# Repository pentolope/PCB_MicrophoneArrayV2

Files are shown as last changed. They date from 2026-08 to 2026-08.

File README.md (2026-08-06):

# 16-channel circular PDM microphone array

A 120 mm circular, four-layer KiCad 10 carrier for sixteen `MSM261DHP006` PDM
MEMS microphones running at 3.3 V. A socketed Sipeed Tang Nano 9K performs
acquisition and decimation; a 2012 Raspberry Pi Model B collects the audio over
SPI0 over a 26-way cable to the Pi's P1 header.

The sixteen acoustic ports sit on a 54.00 mm radius at 22.5 degree intervals,
channel 0 on +X, numbered counter-clockwise viewed from the component side.

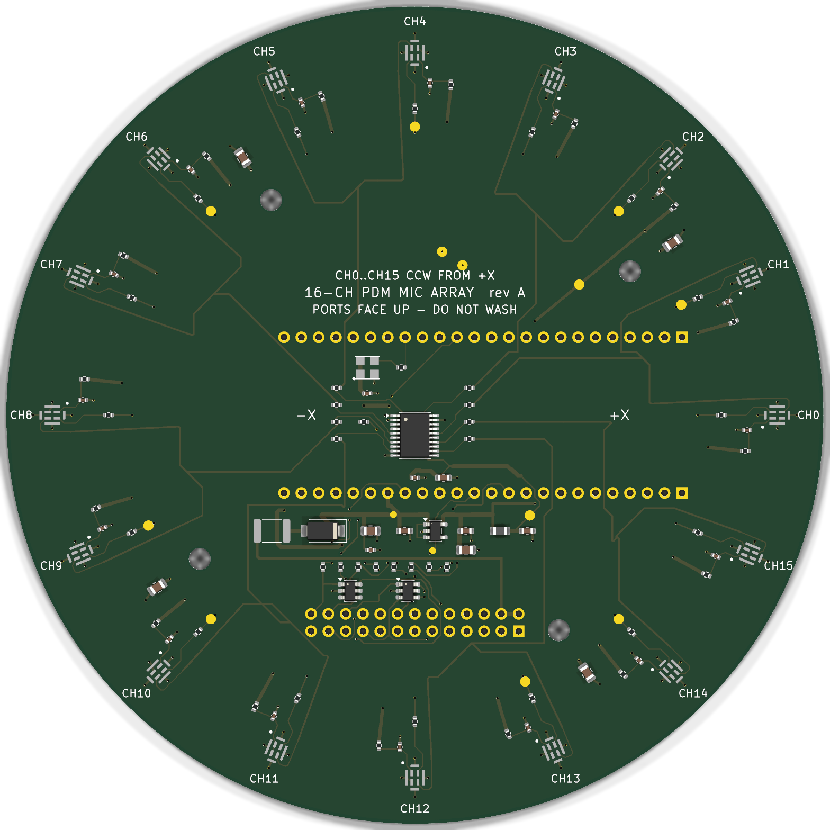
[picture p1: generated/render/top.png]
top side


## Design summary

| | |
|---|---|
| Board | 120 mm circle, 1.6 mm, 4 layers, ENIG, green / white |
| Stackup | signal / GND / GND / signal - both inner layers solid ground |
| Microphones | 16 x `MSM261DHP006`, top-ported, 3.3 V, ports up at the rim |
| Channel pairing | adjacent channels share a data line by clock edge, 8 data nets |
| Reference clock | 24.576 MHz oscillator to a global-clock FPGA pin |
| PDM clock | 3.072 MHz, buffered to 8 series-terminated branches |
| Sample rate | 48 kHz after decimate-by-64 |
| Level translation | none - microphones, FPGA banks and Pi GPIO are all 3.3 V |
| Power | Raspberry Pi 5 V only, via PTC and series Schottky |
| Microphone supply | `LP5907MFX-3.3`, 10 uVrms, 82 dB PSRR at 1 kHz |
| Host link | SPI0, 25 MHz design target, ESD-protected and series-damped |
| Assembly | all SMT on top; module sockets and Pi header hand-soldered |

The `MSM261DHP006` is a top-ported part, so "outward-facing" is realised as
ports facing up at the rim rather than radially. The capsules are
omnidirectional, so the array response is set by the port geometry, not by
package orientation; the alternative - sixteen perpendicular daughter-cards -
cannot be assembled by JLCPCB. This is discussed in
[docs/architecture.md](docs/architecture.md).

## Documentation

- [docs/architecture.md](docs/architecture.md) - signal, clock, power and
  stackup decisions, Tang Nano 9K pin assignments, and known limitations.
- [docs/host-interface.md](docs/host-interface.md) - Raspberry Pi pinout,
  bandwidth analysis and the wire protocol.
- [docs/routing.md](docs/routing.md) - what is pre-routed and why, the
  microphone escape geometry, and the FreeRouting invocation including three
  version-specific workarounds that fail silently if omitted.
- [docs/manufacturing.md](docs/manufacturing.md) - order options, order remark,
  microphone handling limits and bring-up sequence.
- [docs/sources.md](docs/sources.md) - every datasheet and manufacturer rule the
  design relies on, with the facts taken from each.

## Repository layout

| Path | Contents |
|---|---|
| `microphone_array_v2.kicad_sch` | generated schematic - do not hand-edit |
| `microphone_array_v2.kicad_pcb` | generated board - do not hand-edit, see below |
| `microphone_array_v2.kicad_pro` | project settings, net classes, design rules |
| `MicArrayV2.kicad_sym` | generated project symbols |
| `MicArrayV2.pretty/` | project footprints: microphone, oscillator, silk-free probe pads |
| `constraints.json` | frozen requirements and manufacturing profile |
| `tools/` | design source of truth, generators and checkers |
| `docs/` | engineering documentation |
| `generated/` | reports, renders and release artefacts |

## Source of truth

`tools/netlist.py` holds the complete component list, netlist and placement.
The schematic and the board are both generated from it. Nothing about the
board is edited by hand; see [the build](#building-the-board) below. Three
independent gates keep schematic and board in step:

- `tools/check_netlist_parity.py` extracts the netlist from the generated
  schematic with `kicad-cli` and compares it against `netlist.py`, including an
  exact match on which pins are deliberately left unconnected.
- KiCad's `--schematic-parity` DRC compares the board against the schematic.
- `tools/check_placement.py` re-derives the array geometry from the board:
  every microphone's acoustic port radius and azimuth, every Tang Nano 9K
  socket pin coordinate, courtyard overlaps by exact polygon distance, JLCPCB
  package-pair body spacing, and edge clearance.

`tools/check_routes.py` adds the post-route constraints KiCad cannot express:
allowed layers per net, via budgets on the clock nets, branch length matching
across the eight microphone pairs, different-net crossings, and acid traps -
corners left with an interior angle under 90 degrees.

Regeneration commands are in [docs/manufacturing.md](docs/manufacturing.md).

## Building the board

One command, from an empty directory, start to finish:

```bash
"C:/Program Files/KiCad/10.0/bin/python.exe" tools/build.py --install
```

It runs [tools/gen_pcb.py](tools/gen_pcb.py) to produce the pre-route board -
outline, stackup, footprints, placement, zones, net classes, rules, the
solder-mask via keep-outs and the declared critical routing, all locked - then
hands it to KiCad Routing Tools under the recorded plan in
[tools/routing_plan.json](tools/routing_plan.json), refills the zones and puts
the result through KiCad ERC, KiCad DRC, the critical-net contract and the
board's own manufacturability checks. The board is installed only if every gate
passes. Drop `--install` to build and check without touching the project.

Everything the run produced is kept in `build/`: the pre-route board, the routed
candidate, the plan that was executed, every command with its output, and the
validation reports.

Copper is never edited after routing. A failure is fixed in whichever input
caused it - the generator for placement and fanout, the rules or keep-outs for a
manufacturing violation, the critical-route generator for a clock, the routing
plan for anything else - and the board is built again from the beginning.

**Critical routing, and why each is generated rather than routed.** The
requirements come from `critical_routes` in
[constraints.json](constraints.json) and are checked after every build by
[tools/critical_nets.py](tools/critical_nets.py), which runs the validator's own
topology rule:

| Nets | Requirement | Why it is generated |
| --- | --- | --- |
| `MCLK_OSC`, `AUDIO_MCLK` | F.Cu, 0 vias | 24.576 MHz, the fastest edge on the board; a via would add a stub and a layer change in the middle of it |
| `PDM_CLK_FPGA`, `PDM_CLK_IN` | F.Cu, 0 vias | a TSSOP-20 pad row has 0.25 mm between pads, so the fan-in shape is decided by the package |
| `PDM_CLK_B0..7` | matched within 5 mm, F.Cu, 0 vias | inter-channel timing across the array; all eight are routed to one measured target |
| microphone escapes, supply ring, data spokes, ground stitching | mask keep-outs, 0.40 mm to any opening | the 0.566 mm ring corner and the plugged-via rule leave no room for a search |

## Status

**Generated, routed and DRC clean.** KiCad reports 0 DRC violations, 0
unconnected items and 0 schematic parity issues; ERC, netlist parity and the
placement audit all pass. Every via clears its nearest solder-mask opening by at
least 0.40 mm, so the board needs no filled-and-capped or resin-plugged process.
The eight PDM clock branches keep their intended topology - F.Cu only, zero
vias, and now matched to 1.1 mm rather than 24 mm - and both inner layers are
still solid ground.

Fourteen of the twenty-four test points are placed, each on top of a piece of
its own net so it needs no track of its own; the other ten have nowhere on the
top layer to go, and are listed in [docs/status.md](docs/status.md).

A release package is sealed at `generated/release/` — Gerbers, drills, BOM, CPL,
schematic PDF and a SHA-256 manifest, all built from one board revision in a
single run. It is a release *candidate*: JLCPCB's own part orientations cannot
be checked locally, so step through their previews before ordering. See
[docs/manufacturing.md](docs/manufacturing.md).

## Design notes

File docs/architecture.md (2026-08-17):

# Hardware architecture and engineering decisions

## Frozen requirements

- Board: 120.00 mm circular outline, 1.60 mm finished thickness, four copper
  layers, 1 oz outer / 0.5 oz inner copper, ENIG finish, green mask, white
  legend.
- Array: 16 JLCPCB-assembled `MSM261DHP006` PDM microphones running at 3.3 V,
  acoustic ports on a 54.00 mm radius at 22.5 degree intervals, channel 0 on
  +X, numbered counter-clockwise viewed from the component side.
- FPGA: Sipeed Tang Nano 9K in two hand-soldered 1x24 2.54 mm female sockets on
  the board bottom, `J2` (upper row) and `J3` (lower row).
- Host: 2012 Raspberry Pi Model B, 26-pin P1 header, SPI0 transport, on `J1` -
  a 2x13 female socket on the bottom side that mates directly onto the Pi's P1
  pins, no cable.
- Power: Raspberry Pi 5 V only.
- Assembly: every SMT part on the top side. `J1`, `J2` and `J3` are hand-fitted
  and marked DNP; all three take a 1.00 mm drill on a 2.54 mm grid.

### How "outward-facing" is realised

The `MSM261DHP006` is a **top-ported** part: its acoustic port is a 0.325 mm
hole in the lid, so its acoustic axis is normal to the PCB and cannot be made
to point radially outward on a single flat disc. The array is therefore built
with the ports facing up at the rim, on a 54 mm radius. Because the capsules
are omnidirectional, this costs nothing in directivity: the array's spatial
response is set by the geometry of the port positions, not by the orientation
of each package. Each package is additionally rotated so that its port is the
outermost feature of the footprint, with the port sitting exactly on the
54.00 mm circle. `tools/check_placement.py` asserts that radius for all 16
channels on every regeneration.

A literally radial arrangement would need sixteen small daughter-cards soldered
perpendicular at the rim, which cannot be assembled by JLCPCB and was rejected.

## Signal architecture

`MSM261DHP006` (`C22390138`) is a 4.0 x 3.0 x 1.0 mm LGA-8 part specified for
VDD 1.6 - 3.6 V, so 3.3 V is inside its normal operating range and no dedicated
microphone rail voltage is needed.

Adjacent channels form a left/right pair and share one data line. The even
channel straps `L/R` low and drives data on the falling clock edge; the odd
channel straps `L/R` high and drives on the rising edge. Sixteen microphones
therefore reach the FPGA on eight data nets, `PDM_D0` to `PDM_D7`.

**No level translation is used anywhere.** The microphones, the Tang Nano 9K
3.3 V banks and the Raspberry Pi GPIO are all 3.3 V logic. The microphone
guarantees V_OH = VDD - 0.45 V = 2.85 V against the FPGA's 2.0 V LVCMOS33 input
threshold, and accepts V_IH = 0.7 x VDD = 2.31 V against the FPGA's 3.0 V-plus
output. This removes the two 8-bit translators and one single-bit translator
that a 1.8 V microphone rail would have required.

Each microphone output has its own 22 ohm series resistor before the pair join,
so both drivers on a shared net are source-damped. Each microphone supply pin
is fed through a 100 ohm resistor with a local 100 nF capacitor, which is the
arrangement the datasheet's recommended interface circuit calls for; it forms a
16 kHz supply filter per channel and decouples the sixteen capsules from each
other on the shared rail. Four 10 uF capacitors stabilise the ring.

## Clocking

`OT322524.576MJBA4SL` (`C2831388`) supplies an exact 24.576 MHz LVCMOS clock to
FPGA pin 51 (`GCLKC_3`), a global-clock-capable input. The intended gateware
divides it by 8 to 3.072 MHz and decimates by 64 to 48.000 ksample/s.

An external oscillator is required because the Tang Nano 9K's onboard 27 MHz
reference cannot produce an exact 48 kHz family rate: 3.072 MHz / 27 MHz is
128/1125, and the GW1NR-9C rPLL cannot reach a divider of 1125.

The 3.072 MHz PDM clock leaves the FPGA on pin 35 (`GCLKT_4`), passes a 33 ohm
series resistor and drives all eight inputs of an `SN74LVC244APWR` used as a
fan-out buffer. Its eight outputs each feed one microphone pair through a
33 ohm series resistor. Driving sixteen capsules spread around a 339 mm
circumference from one FPGA pin would present roughly 100 pF of load plus a
long distributed line; the buffer splits that into eight short, individually
terminated branches. Input-to-output skew of the buffer is a few nanoseconds
against a 325 ns clock period, which is irrelevant at this rate, and the
resulting inter-channel sampling skew is far below one part in 10^4 of a
48 kHz sample.

## Power architecture

The only supply path is:

```
J1.2 and J1.4 (Pi P1 5 V) -> F1 500 mA PTC -> D1 SS14 -> +5V
+5V -> J3.18, the Tang Nano 9K 5 V header pin
+5V -> U1 LP5907MFX-3.3 -> +3V3A  (microphone ring)
+3V3A -> FB1 600 ohm bead -> +3V3_CLK  (oscillator and clock buffer)
```

`D1` is in series rather than optional. The Tang Nano 9K's USB-C connector is
still needed to load a bitstream, and its VBUS is tied to the same module 5 V
net that this board feeds. The Schottky lets whichever supply is higher win
while preventing USB VBUS from back-feeding the Raspberry Pi's 5 V rail, so a
programming cable can be plugged in without contention. `F1` protects the Pi's
own polyfuse against a fault on this board.

`U1` is an `LP5907MFX-3.3/NOPB` chosen for 10 uVrms output noise and 82 dB PSRR
at 1 kHz, feeding only the microphone ring. The oscillator and the clock buffer
are the noisy loads, so they are filtered off the same regulator through a
ferrite bead rather than the microphones being filtered from them; that puts
the filter at the aggressor.

Estimated draw: 16 microphones about 24 mA, oscillator about 15 mA, buffer
about 6 mA, Tang Nano 9K about 150 mA, total about 200 mA. This is within what
an original Model B's 5 V rail can pass, but the Pi must be fed from a supply
of at least 1.5 A. See [manufacturing.md](manufacturing.md) for the bring-up
sequence.

## Tang Nano 9K assignments

Two sets of designators are in play and they are easy to confuse. Sipeed's own
schematic calls the module's header rows **J5** and **J6**; the sockets on
*this* board that receive them are **J2** and **J3**. `J2` takes the module's
J5 row and `J3` takes its J6 row, position for position, position 1 being the
USB-C end on both. The table below is in this board's designators, because the
signal names in it are this board's nets - consult
[sources.md](sources.md) when reading Sipeed's diagram alongside it.

Only 3.3 V bank pins are used. `J3` positions 2 to 9 - the module's J6.2 to
J6.9 - are FPGA bank 3 at 1.8 V and are deliberately left unconnected, as are
the TF-card and HDMI-multiplexed pins.

Two rules set the assignment. The eight data lines are spread across **both**
header rows and ordered along each row to follow the azimuth of the channels
they serve: the four upper pairs land on `J2` and the four lower pairs on `J3`.
Putting all eight on adjacent pins of one row forces every line from the lower
rim to travel the length of the module and cross its neighbours. Separately,
**every host signal is on `J3`**, the row facing the Pi header, and **both
clocks are on `J2`**; leaving SPI on the upper row made those lines cross the
whole board, out from `J1` at the bottom, past the header and both socket rows,
to reach it.

| Carrier signal | Module header | FPGA pin | Direction |
|---|---:|---:|---|
| `PDM_D0` (CH0/1, azimuth 11 deg) | J2.5 | 25 | input |
| `PDM_D1` (CH2/3, 56 deg) | J2.9 | 29 | input |
| `PDM_CLK_FPGA` | J2.14 | 35 (`GCLKT_4`) | output |
| `AUDIO_MCLK` | J2.17 | 51 (`GCLKC_3`) | input, global clock |
| `PDM_D2` (CH4/5, 101 deg) | J2.19 | 54 | input |
| `PDM_D3` (CH6/7, 146 deg) | J2.23 | 68 | input |
| `PDM_D7` (CH14/15, 326 deg) | J3.1 | 63 | input |
| `PDM_D6` (CH12/13, 281 deg) | J3.10 | 77 | input |
| `HOST_SYNC` | J3.11 | 76 | output |
| `HOST_STATUS` | J3.13 | 74 | output |
| `SPI_MOSI` | J3.14 | 73 | input |
| `HOST_IRQ` | J3.15 | 72 | output |
| `SPI_CS_N` | J3.16 | 71 | input |
| `HOST_RESET_N` | J3.17 | 70 | input |
| `+5V` | J3.18 | power | input to module |
| `SPI_SCLK` | J3.19 | 48 | input |
| `SPI_MISO` | J3.20 | 49 | output |
| `PDM_D5` (CH10/11, 236 deg) | J3.21 | 31 | input |
| `PDM_D4` (CH8/9, 191 deg) | J3.22 | 32 | input |
| `GND` | J3.23 | power | return |
| `TANG_3V3` | J3.24 | power | ESD clamp reference only |

The host block on `J3.11` to `J3.20` is in the same left-to-right order as the
series-damping resistor row that feeds it, so those runs do not cross.

FPGA pins 68, 70, 71, 72 and 75 are shared with the module's HDMI connector.
Four of them are used - 68 (`PDM_D3`), 70 (`HOST_RESET_N`), 71 (`SPI_CS_N`) and
72 (`HOST_IRQ`) - and driven as ordinary 3.3 V GPIO they carry an unterminated
stub to that connector, which is immaterial at the 3.072 MHz PDM rate and for
the DC-ish control lines. Pin 75 is not used at all. Both clock inputs are kept
off HDMI-shared pins, and so are the two 25 MHz SPI signals whose edges the
link actually depends on, `SPI_SCLK` (48) and `SPI_MISO` (49). `SPI_CS_N` is
the one SPI line on a shared pin; it is static for the duration of a burst. The
microSD pins (`J2.1`-`J2.4`) are left alone so the module's card socket stays
usable.

Socket position 1 is the module's USB-C end on both rows, matching Sipeed's
published pin diagram. `tools/check_placement.py` asserts that `J2` and `J3`
land on their expected board coordinates, and the net assignment above is
generated from `TANG_NET_MAP` in `tools/design.py`, which is the authority for
it.

### Known limitation: module ground return

The Tang Nano 9K exposes exactly one ground pin across both header rows
(`J3.23`). Every signal between the carrier and the module shares that single
return. This is a property of the module, not of this board. It is mitigated by
keeping both inner layers as solid ground directly under the module, by series
damping every fast net, and by keeping the SPI runs between the module socket
and the host header short. It remains the weakest part of the interconnect and is the
first thing to examine if high-rate SPI proves marginal.

## Layer usage and return paths

| Layer | Function |
|---|---|
| `F.Cu` | All components, primary routing, all clock nets |
| `In1.Cu` | Solid ground plane |
| `In2.Cu` | Solid ground plane |
| `B.Cu` | Secondary routing; no components |

This deliberately departs from the more usual signal / ground / power / signal
arrangement. The whole board draws about 200 mA, so the supplies are entirely
comfortable as 0.6 mm tracks, and dedicating the second inner layer to ground
instead buys an unbroken reference plane adjacent to **both** routing layers.
No PDM clock or data line can then cross a plane split, and the return current
for any trace on either outer layer has a continuous path directly beneath it.
Power-plane impedance, which is what the conventional stackup would buy, is not
a constraint at this current.

Ground is a plane net that the autorouter never sees. Because a plane on an
inner layer cannot reach a surface-mount pad on its own, `tools/gen_pcb.py`
places an explicit stitching via plus a short connecting track at every ground
pad - 110 of them - choosing each via position by scoring candidate directions
against all neighbouring pads rather than by a fixed offset.

Track widths come from net classes: 0.60 mm for supplies, 0.25 mm for the
per-channel microphone feeds and the clock nets, 0.20 mm elsewhere. Routing
vias are 0.45 mm pad on a 0.30 mm finished hole and are tented on both sides.
Copper-to-edge target is 0.30 mm.

## Test provisions

Twenty-four top-side test pads on two arcs expose the three supply rails, the
Tang 3.3 V sense, two grounds, the 24.576 MHz reference, the 3.072 MHz PDM
clock, all eight PDM data lines and all eight host signals. Each is labelled on
the silkscreen with a short mnemonic; the full net name is carried on the
fabrication layer.

## Primary sources

See [sources.md](sources.md) for the datasheets, JLCPCB capability pages and
Sipeed documentation this design was built from, with retrieval dates.

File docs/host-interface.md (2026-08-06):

# Raspberry Pi host interface

## Physical connection

`J1` is a 2x13, 2.54 mm pin header on the board bottom, hand-soldered and
marked DNP for assembly. A 26-conductor cable connects it to the P1 header of
a 2012 Raspberry Pi Model B. Pin 1 is marked on the silkscreen and by a square
pad.

Mating the two boards directly instead, which the HOST_DIRECT_STACK contract
asks for, is the better link electrically - it would remove about 150 mm of
unshielded cable and its shared return - but it is not a connector swap. It
needs the host fan re-laid for a socket's mirrored pin rows, and it needs the
Tang Nano 9K off the underside, because that is where the Raspberry Pi would
be. Recorded in [status.md](status.md).

Only pins that are identical on Model B revision 1.0 and revision 2.0 are used,
so the board works with either. In particular the revision-dependent pins 3, 5
and 13 are left unconnected, and the P5 header carrying I2S is not used at all -
that header does not exist on revision 1.0 boards.

| Pi physical pin | BCM signal | Array function | Direction at Pi |
|---:|---|---|---|
| 2, 4 | 5V | board supply | power out |
| 6, 9, 14, 20, 25 | GND | return | power |
| 16 | GPIO23 | `HOST_SYNC` | input |
| 18 | GPIO24 | `HOST_STATUS` | input |
| 19 | GPIO10 / MOSI | `SPI_MOSI` | output |
| 21 | GPIO9 / MISO | `SPI_MISO` | input |
| 22 | GPIO25 | `HOST_IRQ` | input |
| 23 | GPIO11 / SCLK | `SPI_SCLK` | output |
| 24 | GPIO8 / CE0 | `SPI_CS_N` | output |
| 26 | GPIO7 / CE1 | `HOST_RESET_N` | output |

Pin 1 (3V3) is deliberately **not** connected. The ESD arrays clamp to the
board's own `TANG_3V3` rail instead, which is present whenever the board is
powered; clamping to the Pi's 3.3 V would pull the signals towards 0.7 V if the
Pi were unpowered while the module was running from USB.

Every host line carries a 33 ohm series resistor at the connector and passes
through one of two `USBLC6-4SC6` four-channel ESD arrays.

## Bandwidth and clock rate

The sustained payload at full rate is

```
16 channels x 48000 samples/s x 16 bits = 12.288 Mbit/s
```

A 2012 Model B drives SPI0 from a 250 MHz core clock divided by an even
integer, so the usable settings near the top are 15.625 MHz (divider 16) and
25 MHz (divider 10).

- At **25 MHz** the payload occupies about 49 % of the link, which leaves
  comfortable headroom for framing and for the Pi's DMA servicing.
- At **15.625 MHz** it occupies about 79 %, which is workable but tight.
- Decimating to 16 kHz in the FPGA instead reduces the payload to 4.096 Mbit/s
  and runs comfortably at any supported clock.

The hardware is designed for 25 MHz: series damping on every line, ESD arrays
with 3 pF loading, and short runs between the socket and the connector. Whether
25 MHz is actually reliable depends on cable length and on the single-ground
return described in [architecture.md](architecture.md); treat 16 kHz mode as
the fallback if it is not.

## Proposed wire protocol

This repository freezes the electrical interface and pin constraints. The
gateware implementation can evolve without a board revision.

- SPI mode 0, MSB first, 25 MHz maximum.
- The FPGA raises `HOST_IRQ` when at least one complete frame is buffered.
- The Pi asserts `SPI_CS_N` and clocks a fixed 32-byte header followed by the
  payload.
- `HOST_RESET_N` is active low and resets the acquisition FIFO without
  reconfiguring the FPGA.
- `HOST_SYNC` pulses on the first sample of a frame; `HOST_STATUS` is high while
  acquisition is locked to the 24.576 MHz reference.

Header fields are little-endian after the byte-oriented magic:

| Offset | Size | Field |
|---:|---:|---|
| 0 | 4 | ASCII `PDM1` |
| 4 | 2 | protocol version, initially 1 |
| 6 | 2 | header size, 32 |
| 8 | 4 | frame sequence number |
| 12 | 4 | sample sets in payload |
| 16 | 8 | running 48 kHz sample counter |
| 24 | 4 | status flags: overflow, clock fault, reset seen |
| 28 | 4 | CRC-32 of payload, or zero when disabled |

The payload is interleaved signed 16-bit PCM: sample set 0 channels 0 to 15,
then sample set 1, and so on. Channel *n* is the microphone whose acoustic port
lies at azimuth 22.5*n* degrees counter-clockwise from +X.

## Channel-to-edge mapping in gateware

Each PDM data line carries two channels multiplexed by clock edge:

| Data net | Falling edge (`L/R` low) | Rising edge (`L/R` high) |
|---|---|---|
| `PDM_D0` | CH0 | CH1 |
| `PDM_D1` | CH2 | CH3 |
| `PDM_D2` | CH4 | CH5 |
| `PDM_D3` | CH6 | CH7 |
| `PDM_D4` | CH8 | CH9 |
| `PDM_D5` | CH10 | CH11 |
| `PDM_D6` | CH12 | CH13 |
| `PDM_D7` | CH14 | CH15 |

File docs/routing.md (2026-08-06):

# Routing methodology

> **The router is now KiCad Routing Tools, driven by
> [tools/routing_plan.json](../tools/routing_plan.json) from
> [tools/build.py](../tools/build.py).** The FreeRouting flow described from
> *Exporting* onwards is kept as the record of how Rev A was first routed; it
> is not the flow in use. See "Building the board" in the
> [README](../README.md).

## Authority

KiCad owns the board. The router may add tracks and vias and nothing else.
Every candidate is routed into a *copy* of the pre-route board, and the build
compares the two: footprints, outline, netlist, stackup and origin must be
untouched, or the candidate is rejected.

## What is pre-routed, and why

Three classes of copper are placed deterministically by `tools/gen_pcb.py`
rather than by the autorouter:

**Ground stitching.** Ground is a plane net that the autorouter is told to
ignore, and an inner plane cannot reach a surface-mount pad by itself. Every
ground pad therefore gets its own via plus a short connecting track. Via
direction is chosen along the pad's own axes, never diagonally: a diagonal
crosses the neighbouring pin on a fine-pitch package, and on the microphone it
lands in the corner channel the signal pads need.

**Microphone L/R straps.** Pad 2 sits inside the ground ring with a 0.40 mm gap
around it, so it cannot reach a via of its own, and it must not consume one of
the four diagonal corners. It is always on the same net as a neighbour it can
be joined to directly: ground (pad 6) on even channels, the supply pad on odd
channels.

**Microphone escapes.** This is the critical one. The `MSM261DHP006` land
pattern encloses its four signal pads in a ring of ground pads. The straight
gaps are 0.40 mm, which fits no track at all once clearance is counted. The
only way out is the diagonal corner between a side bar and an end bar, which
measures 0.566 mm - enough for a 0.15 mm track with 0.15 mm clearance and
nothing more.

FreeRouting cannot handle those corners in either direction:

- It will not create the escapes itself. It approximates pad outlines with
  bounding octagons (`ShapeSearchTree45Degree.complete_shape: non-IntOctagon
  contained shape, using bounding octagon approximation`), which closes the
  diagonal gap. Left to itself it reports "no connection was found between
  their nets" and finishes with all sixteen microphone clock and data nets
  unrouted.
- It will not accept them as existing wiring either. Given a DSN containing
  them it stalls indefinitely at `Wiring: normalization of net 'PDM_CLK_B3'
  failed` and never starts a routing pass.

The resolution is a handover point. The board given to the autorouter
(`gen_pcb.py --no-escapes`) contains, for each microphone:

- a **via** on each of the three signal nets, sitting where that escape will
  end, just outside the package. A bare via is geometry FreeRouting handles
  without complaint, so it happily routes the rest of each net up to it;
- a **keepout rule area** covering the corridor between the ring and those
  vias, so nothing else is routed through the space the escapes need.

After the candidate is merged, `tools/apply_escapes.py` deletes the keepouts
and draws the escapes into the corridor they reserved, terminating exactly on
the handover vias.

Applying the escapes without reserving the corridor first does not work: the
autorouter fills that space with other nets, and the result came back with 57
shorting-item violations and 103 crossing tracks.

The geometry is identical for all sixteen channels and is generated in
footprint-local coordinates:

| Pad | Path |
|---|---|
| 1 (VDD) | inward through the pad 5 / pad 6 corner |
| 4 (DATA) | inward through the pad 5 / pad 8 corner |
| 3 (CLK) | outward through the pad 7 / pad 8 corner, then up the outside of the left ground bar |

The clock pad needs the detour because it sits on the outward half of the
package while its resistor is inboard. Every corner waypoint is the exact
midpoint of the 0.566 mm gap, giving 0.208 mm to each ground pad, and every
segment is at 45 degrees or orthogonal.

The per-channel 100 nF capacitor is rotated 180 degrees so that its ground pad
- and therefore its stitching via - faces radially inward instead of sitting in
the clock escape corridor.

## FreeRouting invocation

FreeRouting 2.2.4 is pinned by SHA-256 (see [sources.md](sources.md)).

```
java -Xss256m -Xmx6g -jar freerouting-2.2.4.jar --gui.enabled=false \
     -de board.dsn -do board.ses -drc fr-drc.json \
     -mp 6 -mt 4 -inc PLANE
```

`-Xss256m` is required, not an optimisation. With the default thread stack,
FreeRouting 2.2.4 dies about two seconds after loading this board with a
`StackOverflowError` in `PolylineTrace.combine`, recursing on the pre-routed
microphone escapes. The recursion is deep rather than infinite, so a larger
stack clears it; without the flag no candidate is produced at all.

Two constraints have to be applied to the DSN rather than the command line,
because **this version silently ignores the options that would express them**:

- `--router.layers.routable=true,false,false,true` is rejected with
  "Unknown settings property: router.layers.routable ... No field found with
  name or SerializedName: layers", and routing proceeds on all four layers -
  including both ground planes. `tools/patch_dsn.py` instead rewrites the two
  inner layers from `(type signal)` to `(type power)`, which FreeRouting does
  honour.
- KiCad does not carry a track's locked flag into the DSN; every wire exports
  as `(type route)`, which FreeRouting is free to rip up. The same script
  promotes them to `(type protect)`.

`-random_seed` is also rejected by this version, so candidates are varied by
pass count rather than by seed.

Always check the FreeRouting log for `Unknown command line argument` and
`Unknown settings property` warnings. They are warnings, not errors, and the
run continues with the constraint silently dropped. The first routing attempt
on this board ran to completion on all four layers, ground planes included,
because of exactly that.

## End-to-end sequence

```bash
python tools/gen_pcb.py --no-escapes
python tools/kicad_specctra.py export microphone_array_v2.kicad_pcb generated/route/board.dsn
python tools/patch_dsn.py generated/route/board.dsn GND1 GND2
java -Xss256m -Xmx6g -jar freerouting-2.2.4.jar --gui.enabled=false \
     -de generated/route/board.dsn -do generated/route/seed17.ses \
     -drc generated/route/fr-drc.json -mp 6 -mt 4 -inc PLANE
python tools/kicad_specctra.py import microphone_array_v2.kicad_pcb \
     generated/route/seed17.ses generated/route/routed17.kicad_pcb
python tools/merge_routing.py microphone_array_v2.kicad_pcb \
     generated/route/routed17.kicad_pcb generated/route/merged17.kicad_pcb
python tools/kicad_specctra.py compare microphone_array_v2.kicad_pcb \
     generated/route/merged17.kicad_pcb        # must report invariants_equal
python tools/apply_escapes.py generated/route/merged17.kicad_pcb
python tools/check_routes.py generated/route/merged17.kicad_pcb
```

## Why the candidate is merged rather than used directly

**KiCad's SES import must not be allowed to own placement.** Specctra stores
component rotation in whole degrees, and KiCad re-applies the session file's
placement on import. This board is built on 22.5 degree steps, so importing a
candidate silently rounds 33.75 degrees to 34.0 and moves 88 of the 134
footprints. The invariant comparison catches it - `changed_invariants:
["footprints"]`.

`tools/merge_routing.py` therefore keeps the pre-route board as the authority
for footprints, outline, zones and nets, and transplants only the tracks and
vias from the candidate. After merging, the semantic snapshot hash matches the
pre-route board exactly.

Re-running `gen_pcb.py` regenerates the board from the netlist and discards all
routing, so it must not be run after a candidate has been promoted.

## Post-route gates

`tools/check_routes.py` enforces the constraints KiCad's DRC cannot express:

- tracks only on `F.Cu` and `B.Cu`;
- `AUDIO_MCLK` and `MCLK_OSC` on `F.Cu` with zero vias;
- via budgets on the PDM clock nets;
- length spread across the eight clock branches within 6 mm;
- no segment shorter than 0.05 mm and no corner sharper than 45 degrees;
- the ground stitching still intact.

KiCad's own DRC is then the authority for clearance, shorts, holes, edge
clearance and schematic parity, run with `--all-track-errors`,
`--schematic-parity`, `--severity-all` and zero tolerated violations.

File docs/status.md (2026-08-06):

# Status: routed, DRC clean, release sealed

All 270 connections are routed. KiCad reports **0 DRC violations, 0 unconnected
items and 0 schematic parity issues**, with zones refilled. A fabrication
package is sealed at `generated/release/`; see
[manufacturing.md](manufacturing.md).

| Gate | Result |
|---|---|
| Schematic ERC | 0 violations |
| Board DRC (errors + warnings) | 0 violations |
| Unconnected items | 0 |
| Schematic parity | 0 issues |
| Netlist parity, schematic vs `tools/netlist.py` | clean, 83 nets, 124 components |
| Placement and array geometry audit | clean, 124 footprints |
| Clock branch layers and via budget | clean - zero vias, F.Cu only |
| Clock branch length matching | 21.5 mm spread against a 25 mm limit |
| PDM data length | clean |
| Different-net crossings | none |
| Acid traps (interior angle < 90 deg) | none |
| Track segments under 0.05 mm | none |

Copper: 2555 mm over 1000 segments, 184 vias. Both inner layers are still solid
ground, no tracks on either. 124 footprints, including 14 probe pads.

## How it got here

The generated routing in `tools/gen_pcb.py` closed the microphone array, the
clock tree, the data spokes, the supply ring and the power block, but left the
host block open - 73 connections. Those were finished with an external
autorouter, and the test points were removed at the same time. Fourteen of
them are now back, placed against the routed copper - see below.

The autorouter left the parts that matter alone. All eight PDM clock branches
are still F.Cu only with zero vias, and each PDM data net still uses exactly
two. Net classes, via geometry (0.45 mm pad / 0.30 mm drill throughout) and the
ground planes came through untouched.

## What was repaired afterwards

`tools/patch_board.py` fixes the board in place, because it is no longer
regenerated from the netlist. It found and fixed:

- **Two hard shorts.** A ground stitching via and its stub sat on U1 pin 3, tying
  the regulator's enable pin to ground - the whole 3.3 V rail would have been
  dead. Another shorted the 5 V input lane to ground. Both come from the
  `POWER_ROW_REFS` special case in `place_ground_stitching()`, which pushes the
  via 1.45 mm straight down with no obstacle test at all, even though the
  function builds an obstacle list a few lines earlier. Moving
  `POWER_ROW2_Y` from -20.2 to -19.8 mm, to open the 5 V lane, is what put the
  second one on top of that lane.
- **A third instance of the same defect**, 0.067 mm from RH4's SPI_MISO pad.
- **Three clearance failures caused by a single wrong constant.** The generator
  checks everything against `TRACK_CLEARANCE = 0.15`, but POWER wants 0.25 mm and
  Default 0.20 mm, so near misses against those nets passed the guard and
  failed DRC. The +3V3A feed threading the module socket needed 1.30 mm of the
  1.27 mm between two pins; it is now 0.25 mm wide and fits.
- **A dangling 1.6 mm tail** on the +5V bus, left over from turning D1 round so
  its anode faces the fuse.
- **Two 0.3 mm drills 0.204 mm apart** where the supply feed landed on its own
  via next to the ring's. Same net, so the feed now runs into the ring's via.

## Test points

14 of the 24 are back, placed by `tools/place_testpoints.py`. It does not put
them on a ring any more. Each pad goes **on top of a piece of its own net that
is already routed**, so it needs no track of its own - which turns the problem
from "can this be wired" into "is there room", and removes any chance of a
probe pad shorting something on the way to its net. GND is the exception: the
planes run under the whole board, so its two pads take a via of their own and
can go anywhere clear.

A candidate has to clear every other net by that pair's net class clearance,
keep its courtyard out of every other courtyard, stay outside the Tang Nano's
70 x 26 mm outline so a probe can physically reach it, and hold 2.5-3.5 mm from
the other pads. Where a 1.5 mm pad will not fit, a 1.0 mm one is tried.

The pads carry no silkscreen - the stock outline collides with the legend of
whatever they are tucked beside - so they use silk-free variants saved in
`MicArrayV2.pretty` rather than locally edited copies, which keeps KiCad from
reporting that the board no longer matches its library. Positions are on the
fabrication layer and in `generated/test_points.py`.

**Ten nets have no probe pad.** `AUDIO_MCLK` and `PDM_CLK_IN` live entirely in
the central cluster, underneath the FPGA module, so nothing on the top layer
can reach them. `TANG_3V3`, `SPI_SCLK`, `SPI_MOSI`, `SPI_MISO`, `SPI_CS_N`,
`HOST_IRQ`, `HOST_SYNC` and `HOST_RESET_N` run through the host block, which is
too dense for even a 1.0 mm pad. All eight host signals are still reachable at
the Pi header itself, and the clocks at the module socket pins once the module
is unplugged.

## The cleanup pass

`tools/cleanup_tracks.py` tidied the copper the autorouter left, in four passes
that each stay inside the shape the copper already occupied, so nothing that
passed clearance before could fail after:

| | before | after |
|---|---:|---:|
| Segments under 0.05 mm | 31 | **0** (shortest is now 0.071 mm) |
| Corners with interior angle < 90° | 30 | **2**, both on via copper |
| Segments retracing themselves | 3 | **0** |
| Collinear joins | 78 | 10 |
| Track segments | 1099 | 1000 |

Endpoints within 60 µm are snapped together, which is what removes the slivers -
they are wider than a coincidence tolerance would catch. Collinear pairs merge,
retraces drop, and any corner still turning more than 90° has its tip cut off
by a short chord, splitting it into two corners of half the angle.

The two acute corners that remain sit on vias, where the round pad copper fills
the notch, so there is nothing to trap etchant. `check_routes.py` now tests for
that condition rather than for the old 45° grid rule: the host block came from
an external autorouter and is not on the grid, so a grid rule described a style
the board no longer has. 69 corners are off-grid and none of them is acute.

## Still outstanding

Nothing that fails a gate. Worth knowing:

- **Clock branch spread is 21.5 mm**, up from 7.1 mm, because branches 5 and 6
  take lateral corridors around the host block. Inside the 25 mm limit, and
  21.5 mm of FR-4 is about 130 ps against a 325 ns PDM clock period, but the
  margin is thinner than it was.
- **`PDM_CLK_IN` uses 3 vias.** Its budget was 2 and is now 4, with the reason
  recorded in `check_routes.py`: the buffer's inputs interleave with its outputs
  on 0.65 mm pitch, so the input bus has to leave on the bottom layer. That is a
  different case from a clock branch fanning out into open board, which still
  takes none.
- **The release is a candidate, not approved production data.** Everything that
  can be checked locally has been; what cannot is whether each LCSC part's zero
  orientation in JLCPCB's library matches the rotation in `cpl.csv`. That needs
  their live preview.

## Open: the host connector

`verification/boards/live.json` carries a `HOST_DIRECT_STACK` contract that
requires `J1` to be a female 2x13 socket the array plugs straight onto the Pi
with. The board has a male pin header and a cable. The contract is the better
link electrically, and it is not a footprint swap:

- **The pin rows mirror.** KiCad's `PinSocket_2x13_P2.54mm_Vertical` numbers
  its second row on the opposite side of the first (pin 2 at x = -2.54 rather
  than +2.54) - that mirroring is what lets a socket mate face-to-face with a
  header. Swapping the footprint moves every even pin to the other column, and
  the host resistor fan, which is ordered to leave in signal order, has to be
  re-laid to match. Tried: the generator loses the `PI_5V` feed and every clock
  branch to the reshuffled Pi header band.
- **The Raspberry Pi would be where the Tang Nano 9K is.** `J1`, `J2` and `J3`
  are all on the underside. With a cable that is fine; stacked directly, the
  module in its sockets and the Pi's board occupy the same space under the
  array. Direct stacking needs the module moved to the top side, or standoffs
  and a taller socket, and either is a placement change rather than a wiring
  one.

Until that is decided the board keeps the header and the cable, and
`CONTRACT.CONNECTOR` keeps failing - honestly, because the two really do
disagree.

## Reproducibility

**The board is rebuilt from `tools/netlist.py` on demand.** One command,
`tools/build.py --install`, generates the pre-route board, hands the ordinary
nets to KiCad Routing Tools under the recorded plan, and installs the result
only if every gate passes. Nothing in the `.kicad_pcb` is hand-edited, and the
notes above about patching and cleaning copper describe how the board was first
brought up, not how it is maintained. The schematic is generated the same way,
by `tools/gen_schematic.py`, and netlist parity passes.

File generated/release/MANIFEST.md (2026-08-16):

# Fabrication release manifest

- generated: 2026-08-16T20:39:30.252617+00:00
- kicad: 10.0.5
- constraint profile: jlcpcb-4layer-assembled
- source closure sha256: `bd2afdef6dd0df0d8387ff560c4591d102f493100dba02cb8e9492ddbcf32d9b`

## command

    kicad-cli.exe sch erc --output C:\Users\pentolope\Documents\GitHub\PCB_MicrophoneArrayV2\verification\out\microphone-array-v2-live\attempts\20260816T203906Z-9bcc9db5\work\clean_run\reports\erc.json --format json --severity-all --severity-exclusions --exit-code-violations C:\Users\pentolope\Documents\GitHub\PCB_MicrophoneArrayV2\verification\out\microphone-array-v2-live\attempts\20260816T203906Z-9bcc9db5\work\clean_run\fixture\project\microphone_array_v2.kicad_sch
    kicad-cli.exe pcb drc --output C:\Users\pentolope\Documents\GitHub\PCB_MicrophoneArrayV2\verification\out\microphone-array-v2-live\attempts\20260816T203906Z-9bcc9db5\work\clean_run\reports\drc.json --format json --severity-all --severity-exclusions --all-track-errors --schematic-parity --refill-zones --save-board --exit-code-violations C:\Users\pentolope\Documents\GitHub\PCB_MicrophoneArrayV2\verification\out\microphone-array-v2-live\attempts\20260816T203906Z-9bcc9db5\work\clean_run\fixture\project\microphone_array_v2.kicad_pcb
    kicad-cli.exe pcb export gerbers --output C:\Users\pentolope\Documents\GitHub\PCB_MicrophoneArrayV2\verification\out\microphone-array-v2-live\attempts\20260816T203906Z-9bcc9db5\work\clean_run\generated\gerbers --layers F.Cu,In1.Cu,In2.Cu,B.Cu,F.Paste,B.Paste,F.Silkscreen,B.Silkscreen,F.Mask,B.Mask,Edge.Cuts --no-x2 --no-netlist --use-drill-file-origin --subtract-soldermask C:\Users\pentolope\Documents\GitHub\PCB_MicrophoneArrayV2\verification\out\microphone-array-v2-live\attempts\20260816T203906Z-9bcc9db5\work\clean_run\fixture\project\microphone_array_v2.kicad_pcb
    kicad-cli.exe pcb export drill --output C:\Users\pentolope\Documents\GitHub\PCB_MicrophoneArrayV2\verification\out\microphone-array-v2-live\attempts\20260816T203906Z-9bcc9db5\work\clean_run\generated\gerbers --format excellon --excellon-separate-th --drill-origin plot C:\Users\pentolope\Documents\GitHub\PCB_MicrophoneArrayV2\verification\out\microphone-array-v2-live\attempts\20260816T203906Z-9bcc9db5\work\clean_run\fixture\project\microphone_array_v2.kicad_pcb
    kicad-cli.exe pcb export pos --output C:\Users\pentolope\Documents\GitHub\PCB_MicrophoneArrayV2\verification\out\microphone-array-v2-live\attempts\20260816T203906Z-9bcc9db5\build\cpl.csv --format csv --units mm --side both --exclude-dnp C:\Users\pentolope\Documents\GitHub\PCB_MicrophoneArrayV2\verification\out\microphone-array-v2-live\attempts\20260816T203906Z-9bcc9db5\work\clean_run\fixture\project\microphone_array_v2.kicad_pcb
    kicad-cli.exe sch export bom --output C:\Users\pentolope\Documents\GitHub\PCB_MicrophoneArrayV2\verification\out\microphone-array-v2-live\attempts\20260816T203906Z-9bcc9db5\build\bom.csv --fields ${QUANTITY},Reference,Value,Footprint,LCSC --labels "Quantity,Designator,Comment,Footprint,LCSC Part #" --group-by Value,Footprint,LCSC --exclude-dnp --ref-range-delimiter  C:\Users\pentolope\Documents\GitHub\PCB_MicrophoneArrayV2\verification\out\microphone-array-v2-live\attempts\20260816T203906Z-9bcc9db5\work\clean_run\fixture\project\microphone_array_v2.kicad_sch
    rename "13 file(s)"
    orient "103 placement(s)"
    relabel cpl.csv
    relabel bom.csv

## artifacts

- `microphone_array_v2-revA-fabrication.zip` sha256 `2770680dd784fc3fad6d0e4c3f940c4180ad91361ebe8b3abbd9bba7cd0fa03d`
- `bom.csv` sha256 `a3970d865b3b76677afe0b11b6061156e3be633a50613167887ef8a54fe14563`
- `cpl.csv` sha256 `28091e4dbf5a05e30af72f833839194c67c0aa0f90c6f797d0434fce84e7e807`

## excluded from the archive

- `(none)`: every exported layer was approved

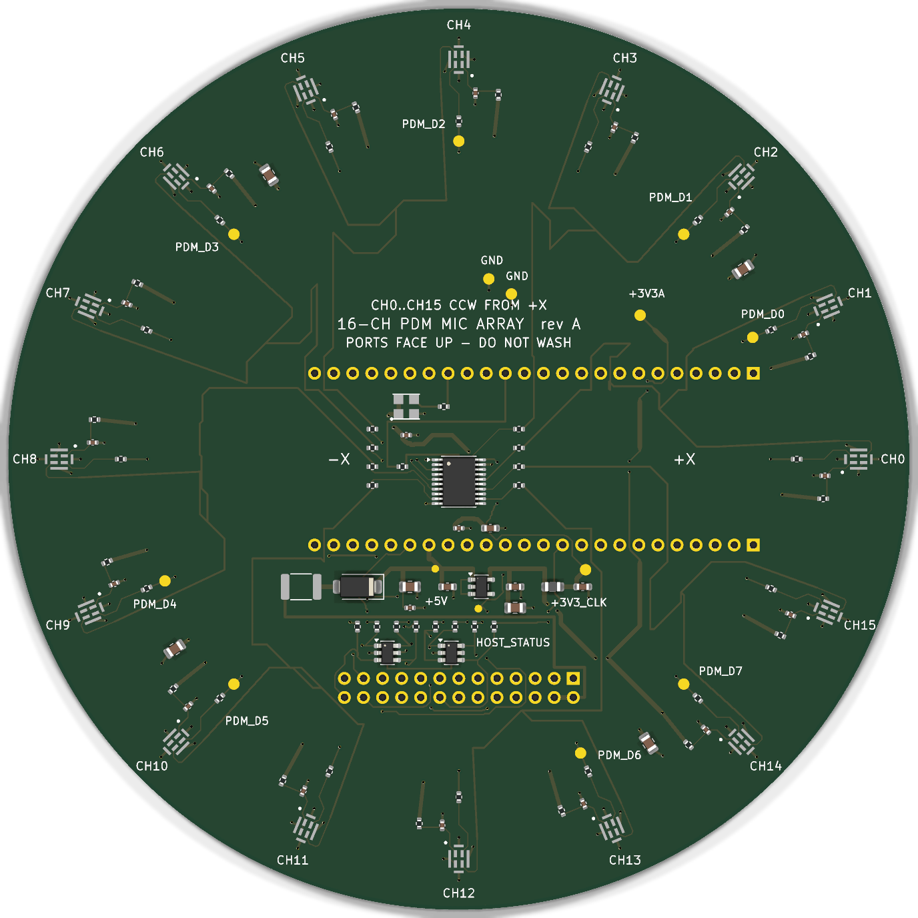
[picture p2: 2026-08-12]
generated/renders/top.png

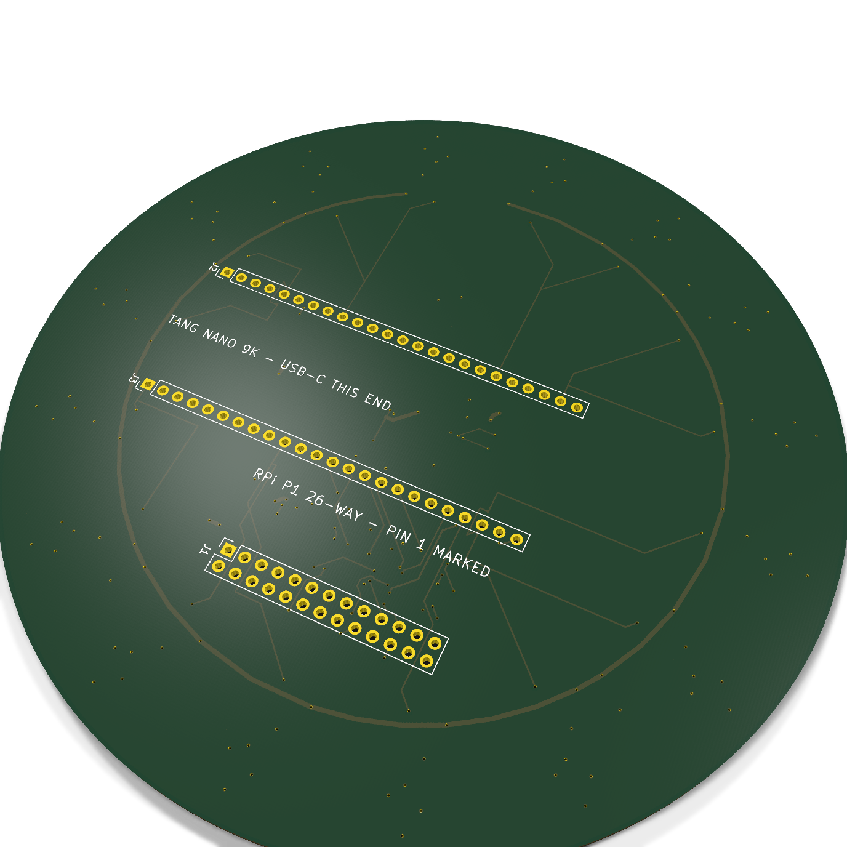
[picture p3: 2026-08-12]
generated/renders/stack_iso.png

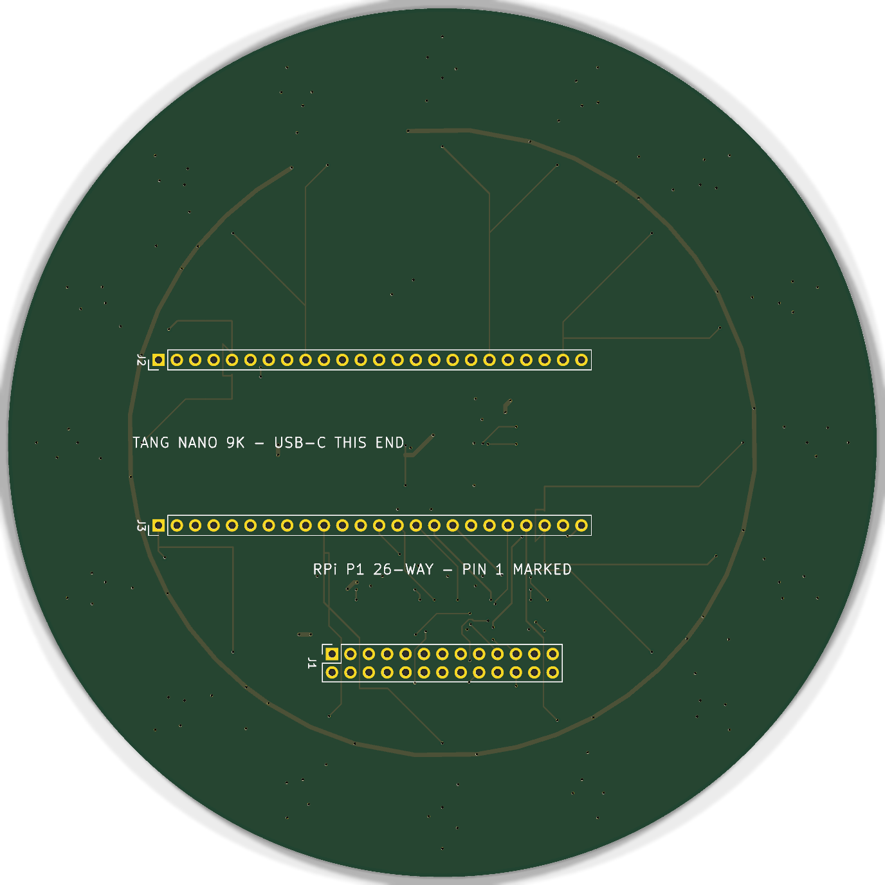
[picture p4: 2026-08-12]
generated/renders/bottom.png

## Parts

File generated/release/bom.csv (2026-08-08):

Comment | Designator | Footprint | LCSC Part # | Quantity
1uF | C1,C2,C7,C9 | Capacitor_SMD:C_0603_1608Metric | C106858 | 4
10uF | C3,CB1,CB2,CB3,CB4 | Capacitor_SMD:C_0805_2012Metric | C15850 | 5
22uF | C4 | Capacitor_SMD:C_0805_2012Metric | C76637 | 1
100nF | C5,C6,C8,CM1,CM2,CM3,CM4,CM5,CM6,CM7,CM8,CM9,CM10,CM11,CM12,CM13,CM14,CM15,CM16 | Capacitor_SMD:C_0402_1005Metric | C1525 | 19
SS14 | D1 | Diode_SMD:D_SMA | C2480 | 1
500mA | F1 | Fuse:Fuse_1812_4532Metric | C369168 | 1
600R@100MHz | FB1 | Inductor_SMD:L_0805_2012Metric | C1017 | 1
MSM261DHP006 | MK1,MK2,MK3,MK4,MK5,MK6,MK7,MK8,MK9,MK10,MK11,MK12,MK13,MK14,MK15,MK16 | MicArrayV2:MSM261DHP006_LGA-8_3x4mm_TopPort | C22390138 | 16
33R | R1,R2,RC1,RC2,RC3,RC4,RC5,RC6,RC7,RC8,RH1,RH2,RH3,RH4,RH5,RH6,RH7,RH8 | Resistor_SMD:R_0402_1005Metric | C25105 | 18
22R | RD1,RD2,RD3,RD4,RD5,RD6,RD7,RD8,RD9,RD10,RD11,RD12,RD13,RD14,RD15,RD16 | Resistor_SMD:R_0402_1005Metric | C25092 | 16
100R | RV1,RV2,RV3,RV4,RV5,RV6,RV7,RV8,RV9,RV10,RV11,RV12,RV13,RV14,RV15,RV16 | Resistor_SMD:R_0402_1005Metric | C25076 | 16
LP5907MFX-3.3 | U1 | Package_TO_SOT_SMD:SOT-23-5 | C80670 | 1
SN74LVC244A | U2 | Package_SO:TSSOP-20_4.4x6.5mm_P0.65mm | C7668 | 1
USBLC6-4SC6 | U3,U4 | Package_TO_SOT_SMD:SOT-23-6 | C111212 | 2
24.576MHz | X1 | MicArrayV2:Oscillator_SMD_YXC_3.2x2.5mm_4Pin | C2831388 | 1

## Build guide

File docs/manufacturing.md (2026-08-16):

# Manufacturing and bring-up

## Release package

`generated/release/`, built by the clean-room release in a single run from one
board revision:

```bash
"C:/Program Files/KiCad/10.0/bin/python.exe" verification/run.py release verification/boards/live.json
```

It copies the project into an empty directory, purges every pre-existing
output, regenerates everything from the native KiCad files with `kicad-cli`,
re-runs the full validation against what it produced, and publishes only if
every gate passes. The BOM and CPL come from the schematic and the board, not
from the Python model that generated them - a released part list has to be
derived from the thing being manufactured.

| File | Contents |
|---|---|
| `microphone_array_v2-revA-fabrication.zip` | 11 Gerbers and 2 Excellon drills, Protel-named |
| `gerbers/` | the same layers unzipped, as exported |
| `bom.csv` | JLCPCB BOM, 15 lines |
| `cpl.csv` | JLCPCB pick-and-place, 103 placements, all top side |
| `MANIFEST.md` | SHA-256 of the archive, board and each data file |
| `reports/` | the ERC and DRC JSON the gates were run against |
| `validation.json`, `clean_room.json` | what was checked, and what produced it |
| `RECEIPT.json` | every file above, with its digest, written last |

Everything in that directory comes from one clean-room run, and
`PROV.RELEASE_COHERENCE` enforces it rather than asserting it:

```bash
"C:/Program Files/KiCad/10.0/bin/python.exe" verification/run.py coherence verification/boards/live.json
```

The check fails if the release manifest describes an archive that is not there,
if the validation report validated a different archive, if any file names a
different source closure from the rest, or if a file is present that the
receipt does not account for.

The review renders - top, bottom, the stacking plan and the four copper
layers - live in [generated/renders/](../generated/renders) rather than in the
release package. The clean-room run purges and never regenerates them, so
keeping them inside the package would contradict the statement in
`UNSEALED.txt` that every file there came from that run.

### Why the layers are named the way they are

The archive says how many copper layers this board has in its **filenames**,
and nowhere else:

| File | Layer | KiCad |
|---|---|---|
| `microphone_array_v2.GTL` | L1, top copper | `F.Cu` |
| `microphone_array_v2.G2L` | L2, inner ground | `In1.Cu`, exported as `.g1` |
| `microphone_array_v2.G3L` | L3, inner ground | `In2.Cu`, exported as `.g2` |
| `microphone_array_v2.GBL` | L4, bottom copper | `B.Cu` |

Layer order used to travel in the Gerber X2 `FileFunction` attributes while the
files themselves were called `GND1.gbr` and `GND2.gbr`. JLCPCB does not
reliably read those attributes, and a board whose inner layers are named after
the net they carry has nothing left that says they are copper at all - it can
be quoted and built as two-layer. So the export now passes `--no-x2`, ships
Protel extensions, and carries no job file: there is exactly one statement of
the stackup and it is the one the fabricator actually reads.

The mapping lives in `fabrication_naming` in
[verification/boards/live.json](../verification/boards/live.json). The release
renames by it, the archive gate admits by it, and `FAB.LAYER_IDENTITY` proves
after every release that the four copper files are present, distinguishable by
name, carrying real geometry, free of X2 attributes - and that `.G2L` and
`.G3L` are geometrically identical to a fresh single-layer export of `In1.Cu`
and `In2.Cu`. Renaming is all that is done to these files; their contents are
KiCad's, byte for byte.

Aperture macros are left enabled. Disabling them made KiCad draw each rounded
pad corner as a single chord instead of an arc, which cost the front mask 1.4%
of its area and chamfered pad corners by up to 0.073 mm. Nothing needed it -
the layer identification is carried entirely by the filenames - so the artwork
keeps its true pad shapes and the export matches the board to within 0.01 mm.

Gerbers, drills and the CPL share one origin. Verified rather than assumed:
`MK1` appears in the CPL at 53.220 mm from the board centre on the +X axis at
270 degrees, which is exactly where the placement puts it, and the Edge.Cuts
outline spans the matching 120 mm.

### Placement angles

Two separate things happen to a rotation on its way from KiCad into `cpl.csv`,
and they are worth keeping apart because confusing them turns parts.

**Normalisation** puts every angle in `[0, 360)`. KiCad writes rotations in
`(-180, 180]`, so half the array arrived as negative numbers; -157.5 and 202.5
are the same orientation, but only one of them goes through without an
engineering query. This changes no part's orientation and applies to all 103
placements.

**Library-zero offsets** do change orientation, and only for parts whose zero
in JLCPCB's library differs from the footprint's zero in KiCad.

Every populated part carries an explicit reviewed entry in the registry at
`release_generation.cpl_orientation.registry` in
[verification/boards/live.json](../verification/boards/live.json) - all fifteen
part numbers, **including the twelve whose offset is zero**. "Nobody has looked
at this one" and "looked at, needs nothing" are different statements and only
the second may ship, so there is no default: generation refuses a part with no
entry rather than quietly assuming zero. An entry counts only when its
`review_status` is exactly `reviewed` - `pending`, `unreviewed`, blank or
absent all block generation, because a half-written entry looks like coverage
and is worse than none. Three parts need a turn:

| LCSC | Part | Package | Offset | JLC library zero vs KiCad |
|---|---|---|---:|---|
| `C80670` | LP5907MFX-3.3 | SOT-23-5 | +180 | pins 1-3 on the right, pin 1 lowest |
| `C7668` | SN74LVC244APWR | TSSOP-20 | -90 | pins 1-10 along the bottom |
| `C111212` | USBLC6-4SC6 | SOT-23-6 | -90 | pins 1-3 along the bottom, pin 1 left |

Entries are looked up by **LCSC number, not by footprint name**, because that
is what the difference is a property of. It matters here: a footprint-regex
table would lump SOT-23-5 in with SOT-23-6 and give the regulator -90 when it
needs 180. Looking them up by part number also makes it impossible for U3 and U4 - the
same device in two places - to be corrected differently.

Each offset was derived from JLCPCB's own library footprint, read through the
EasyEDA API, by comparing every pad against the KiCad footprint rather than
just pin 1: a pin-1 match alone cannot tell a rotation from a mirror. The
retrieval and scoring live in
[tools/jlc_orientation.py](../tools/jlc_orientation.py).

The evidence itself is committed, not summarised. Under
[fabrication/jlc_orientation/](../fabrication/jlc_orientation) each part has two
files: `raw/<LCSC>.json`, the response body byte for byte, and `<LCSC>.json`, a
normalised extract of it recording the source URL, the retrieval date, and the
length and SHA-256 of that body. The extract is a convenience and never an
authority - every offline command re-derives the pads from the raw file and
fails if the extract disagrees. Three things could move an offset and all three
fail: editing the raw body breaks its digest, editing the extract makes it
disagree with the body, and editing the registry makes it disagree with the
score.

```bash
"C:/Program Files/KiCad/10.0/bin/python.exe" tools/jlc_orientation.py check
```

That is offline, as is `report`. Neither the test suite nor a clean release
touches the network, so EasyEDA being down cannot fail a release. The one
command that does look upstream is separate and reports the two failures
apart - exit 1 means the committed evidence is corrupt, exit 2 means JLC has
changed their library since it was frozen, which is a prompt to re-freeze and
re-review rather than a release failure:

```bash
"C:/Program Files/KiCad/10.0/bin/python.exe" tools/jlc_orientation.py check-live
```

`CPL.ORIENTATION` re-scores that frozen evidence on every release and requires
the registry to agree with it, checks the registry covers everything the BOM
and the board say will be fitted, and recomputes each shipped angle as the
board angle plus the reviewed offset, normalised into `[0, 360)` - half-open,
so `0` is a placement angle and `360` is not, including when rounding would
otherwise carry a value up to it. Checking the shipped file against the table
the generator used would only prove a program can apply its own table twice.
`PROV.SOURCE_CLOSURE` separately requires the script, this schema and both
evidence files for all fifteen entries to be inside the release's source
closure, so an input cannot quietly stop being tracked - and, because these
offsets are *derived* rather than read off the board, the code that derives
them is tracked with them. `pcbqa.orientation`, `pcbqa.cleanroom`,
`pcbqa.gates.g_orientation` and `tools/jlc_orientation.py` are hashed from the
modules that were actually imported, not from files at a path, so a stale copy
sitting at a tracked path cannot stand in for the code that ran. Editing any of
them changes the source-closure digest and invalidates every report bound to
it.

The closure is an identity, so it has to mean the same thing on every machine
and a different thing whenever the release would differ. Four things make that
true. Its globs are explicit and exclude the validator's own tree, this board's
output and the routing scratch, so it cannot change because a previous attempt
is still on disk. The files named in `sources` are added by name as well, so
the selected board and schematic are covered because they were selected and not
because a glob happened to reach them - point the release at a different board
and the closure changes. Its digests are canonical, so a checkout with either
line ending is the same design. And the manifest enters as its *content* rather
than as its file digest, minus exactly the leaves the clean room assigns, so
the reports a run produces can still be checked from the repository that
produced them.

That exclusion list is owned by `pcbqa.cleanroom`, not by the board file: a
manifest may name a subset of it and nothing else, so no board can excuse its
own release-affecting configuration from its own provenance. The release
compares the origin and clean-room closures and refuses to publish if they
disagree.

Nothing else takes an offset, and that is measured rather than assumed. When
JLCPCB revised the first production upload they corrected 11 of the 16
microphones, 11 of 16 damping resistors and so on - and the five left alone in
each family were exactly those already sitting at a multiple of 45 degrees. A
library mismatch is a property of the part, so it would have turned all 16.
The clearest case is `C15850`: `C3` at 0 degrees was untouched while `CB1`-`CB4`
- the same part in the same footprint, at fractional angles - were revised. The
frozen library evidence agrees, deriving a zero offset for every one of them.

The other 48 references JLCPCB revised keep the fractional angles this board
submitted - 22.5-degree multiples, because the array is 16-way polar - with
negative values normalised into `[0, 360)` and nothing else done to them. No
rounding policy is invented for them: rounding to a value nobody has seen would
move sixteen microphones off the array geometry to match a guess. **It cannot
be confirmed that those 48 now match what JLCPCB produced**; that would need
their revised CPL, which was never supplied. The list is recorded under
`undocumented_production_edits` in the manifest.

**This is a release candidate, not an approved production file.** Upload the
package and step through JLCPCB's Gerber and pick-and-place previews before
paying for it.

## Order options

| Option | Value |
|---|---|
| Layers | 4 |
| Dimensions | 120 mm diameter circle |
| Thickness | 1.6 mm |
| Outer copper | 1 oz |
| Inner copper | 0.5 oz |
| Surface finish | ENIG |
| Solder mask | Green |
| Silkscreen | White |
| Via covering | Plugged (routing vias only) |
| Assembly | Top side only |
| Impedance control | Not required |

## Order remark

```
Four-layer board: L1 top signal / L2 GND / L3 GND / L4 bottom signal.
Both inner layers are solid ground planes; this is intentional.
Plug only the routing vias, which are 0.30 mm finished hole with 0.45 mm pads
and are tented on both sides. Keep every plated through-hole for the two 1x24
module sockets and the 2x13 pin header open, and keep the four 3.2 mm NPTH
mounting holes open. Follow the supplied layer order and the confirm-production
file.
```

## Assembly notes

- All surface-mount parts are on the **top** side. There are no bottom-side
  SMT parts.
- `J1`, `J2` and `J3` are marked DNP and are excluded from the BOM and CPL.
  They are hand-soldered by the customer from the bottom side.
- The four mounting holes and the twenty-four test pads carry no parts.

### Microphone handling

The `MSM261DHP006` datasheet imposes handling limits that must reach the
assembler:

- Moisture sensitivity level 1.
- Maximum three reflow cycles, peak 260 C.
- **Do not board-wash or clean after reflow.** No aqueous wash, no solvents,
  no ultrasonic cleaning.
- Do not apply compressed air or vacuum over the acoustic port, and do not
  place a pick-up nozzle over the port hole.

The first two lines of the top silkscreen carry `PORTS FACE UP - DO NOT WASH`
for this reason. If the assembler's standard process includes a wash step, the
order must be flagged as no-clean.

## Hand-soldered parts

| Ref | Part | Side | Notes |
|---|---|---|---|
| `J2`, `J3` | 1x24 2.54 mm female header | bottom | 0.900 in row spacing; 1.0 mm drills give about 0.18 mm radial slack per pin |
| `J1` | 2x13 2.54 mm pin header | bottom | pin 1 marked by a square pad and a silkscreen triangle |

Fit the module sockets first, then check the Tang Nano 9K seats freely before
soldering the host header.

## Bring-up sequence

1. Inspect the assembled board: all sixteen microphone ports clear, no residue
   over any port, `U1` and `D1` orientation against the silkscreen.
2. With **no** Tang Nano 9K fitted and the host cable disconnected, apply 5 V to
   test pad `5V` through a current-limited supply. Expect well under 5 mA.
   Confirm `3V3A` reads 3.3 V and `3V3C` reads 3.3 V.
3. Fit the Tang Nano 9K. Power from the Pi. Confirm `TANG` reads 3.3 V.
4. Load a bitstream over the module's USB-C. `D1` prevents the USB supply from
   back-feeding the Pi, so both may be connected.
5. Confirm 24.576 MHz on `MCLK` and 3.072 MHz on `PCLK`.
6. Confirm activity on `D0` to `D7`.

The Raspberry Pi must be fed from a supply of at least 1.5 A. This board adds
roughly 200 mA to the Pi's 5 V rail, which an original Model B's input polyfuse
can pass but a marginal phone charger cannot.

### USB-C access

The module hangs below the board on its sockets, with its USB-C connector
facing +X and about 15 mm of carrier overhanging it. With standard 8.5 mm
sockets there is enough gap for a slim USB-C plug, but a thick overmoulded
cable may not fit. Load the bitstream before final assembly, or use a slim or
right-angle cable.

## Regenerating the design

The schematic and the board are both generated from `tools/netlist.py`, which
is the single source of truth. Nothing in the KiCad files should be hand-edited.

```bash
python tools/gen_symbols.py
python tools/gen_schematic.py
python tools/check_netlist_parity.py
python tools/gen_pcb.py
python tools/check_placement.py
python tools/check_routes.py
```

`check_netlist_parity.py` proves the generated schematic carries exactly the
intended netlist. KiCad's own `--schematic-parity` DRC then proves the board
matches the schematic. Note that regenerating the board discards routing, so
run the generators before routing, not after.

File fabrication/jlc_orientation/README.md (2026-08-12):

# Frozen orientation evidence

What JLCPCB's own library says each part's zero orientation is. The registry in
`verification/boards/live.json` declares an offset per LCSC number; these files
are what those offsets are derived from, and the release re-derives them rather
than believing the registry.

## Layout

    raw/<LCSC>.json     the response body from EasyEDA, byte for byte
    <LCSC>.json         a normalised extract of it

`raw/` holds exactly what the server sent: no re-encoding, no re-indenting, no
trailing newline. Each file is a single line of JSON. Do not reformat them -
their SHA-256 is the evidence.

The extract beside it **is not the response**, and nothing here calls it one.
It exists so the geometry can be read without parsing 8-40 kB of unrelated
product metadata, and every offline command re-derives it from `raw/` and fails
on a disagreement rather than trusting what it says.

## Fields of the extract

| Field | Meaning |
|---|---|
| `kind` | always `normalised extract` |
| `lcsc`, `mpn`, `package` | the part, as the raw response names it |
| `source_url` | the EasyEDA endpoint the body came from |
| `retrieved_utc` | when it was fetched |
| `raw_file`, `raw_bytes`, `raw_sha256` | the body this was derived from |
| `units` | millimetres, top view, Y up |
| `derivation` | which fields of the raw document produced `pads` |
| `pads` | `{pad number: [x, y]}` in millimetres |

`pads` is keyed by **pad number**, which is what ties an electrical pin to a
position: that mapping, not a visual marker, is what decides the offset. Every
pad votes when scoring, because a pin-1 match alone cannot tell a rotation from
a mirror.

EasyEDA stores footprint geometry in units of 10 mil with the canvas Y axis
running downward. Both conversions are applied: `x_mm = field3 * 0.254` and
`y_mm = -field4 * 0.254`.

## Commands

    tools/jlc_orientation.py report      score every frozen part      (offline)
    tools/jlc_orientation.py check       registry against evidence    (offline)
    tools/jlc_orientation.py freeze      re-fetch and rewrite both files
    tools/jlc_orientation.py check-live  frozen evidence vs JLC today

`report` and `check` never use the network, so neither the test suite nor a
clean release depends on EasyEDA being reachable. `check-live` is the only
routine reader of upstream, and it separates the two things that can be wrong:
exit 1 means the committed evidence is corrupt, exit 2 means JLC's library has
moved since it was frozen. Drift is not a release failure - it is a prompt to
re-freeze and re-review the affected offset.

Three ways to break an offset, all of which fail:

* edit `raw/<LCSC>.json`      - the recorded SHA-256 no longer matches
* edit `<LCSC>.json`          - the pads no longer re-derive from `raw/`
* edit the registry's offset  - it no longer matches the scored result

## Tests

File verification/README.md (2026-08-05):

# pcbqa - board-agnostic KiCad / JLCPCB verification

A fail-closed validator that takes a native KiCad project plus a declarative
manifest and produces a machine-readable pass/fail matrix. KiCad is the sole
design authority: nothing is believed because a report, a label or a Python
model says so.

Rev A of the microphone array is preserved here as a **negative regression
fixture**. The suite passes by proving the validator rejects it.

## Three commands

```bash
python verification/run.py selftest
```
```bash
python verification/run.py validate verification/boards/reva.json
```
```bash
python verification/run.py release verification/boards/reva.json
```

`selftest` runs the unit, lifecycle, portability, hygiene and mutation tests.

Every invocation owns one attempt directory and writes nothing outside it:

    out/<board_id>/attempts/<attempt_id>/     work/, build/, diagnostics/
    out/<board_id>/published/<release_id>/    immutable once created
    out/<board_id>/latest.json                pointer, replaced atomically

`validate` exits nonzero on a blocking result and leaves its report in its
attempt. `release` builds the candidate under `build/` and publishes it only
once every mandatory gate has passed, by renaming that directory into
`published/<release_id>` - a name that did not exist before, so no release is
ever overwritten. A failed release removes its own `build/`, keeps
`diagnostics/DO_NOT_ORDER.txt`, and leaves any previously published release
and the `latest.json` pointer byte-identical. Nothing is ever swept from a
sibling attempt or from an earlier release.

Use KiCad's bundled Python (it provides `pcbnew` and `shapely`):
`"C:\Program Files\KiCad\10.0\bin\python.exe"`.

## Layout

| Path | Role |
|---|---|
| `pcbqa/core.py` | statuses, results, manifest, provenance, gate registry, reporting |
| `pcbqa/geom.py` | native pad/mask/via geometry via KiCad's own effective shapes |
| `pcbqa/gerber.py` | independent Gerber X2 + Excellon readers, incl. an aperture-macro interpreter |
| `pcbqa/gates/g_provenance.py` | fixture integrity, source authority, report freshness, ERC/DRC |
| `pcbqa/gates/g_geometry.py` | stackup, via/mask clearance, routing style |
| `pcbqa/gates/g_contracts.py` | net topology, connector, placement, archive, constraint parity |
| `pcbqa/gates/g_assembly.py` | BOM and CPL parity against the native design |
| `pcbqa/gates/g_export_parity.py` | per-object via parity and per-layer copper parity |
| `pcbqa/connectivity.py` | copper graph built from geometric intersection |
| `pcbqa/rules/__init__.py` | reusable rule types: `NetTopologyRule`, `ConnectorContractRule`, `PlacementRule` |
| `boards/*.json` | per-board policy. **All** board identity lives here |
| `fixtures/reva/` | byte-for-byte frozen Rev A + `HASHES.json` |
| `fixtures/portability/` | a structurally different board for the portability test |
| `tests/` | synthetic fixtures, geometry tests, mutation tests, hygiene tests |

`tests/test_suite.py::GenericSourceHygiene` mechanically enforces the split: it
extracts identifiers from every board manifest and fails if any appears in
`pcbqa/`, and it fails if any known Rev A defect count is embedded as a literal
in framework source.

## Onboarding another board

Minimum manifest:

```json
{
  "schema_version": 2,
  "board_id": "my_board",
  "constraint_version": "v1",
  "project_root": "../fixtures/my_board",
  "tools": { "kicad_cli": "<path to kicad-cli>" },
  "sources": { "pcb": "my_board.kicad_pcb" },
  "board_origin_mm": [0.0, 0.0],
  "documentation_globs": [],
  "waivers": []
}
```

That alone runs the geometry-only gates. Every other gate stays
`NOT_APPLICABLE` with a reason until you add its policy block. **Absence is
never a silent pass.**

### Policy blocks and the gates they enable

| Manifest key | Gates enabled |
|---|---|
| `fixture.hash_file` | `PROV.FIXTURE_INTEGRITY` |
| `source_authority` | `PROV.SOURCE_AUTHORITY` |
| `reports` | `PROV.REPORT_FRESHNESS` |
| `checks.erc` / `checks.drc` | `ERC.AUTHORITATIVE`, `DRC.AUTHORITATIVE` |
| `checks.drc.forbidden_severities` | `DRC.NO_SUPPRESSED_RULES` |
| `stackup.expected` | `STACK.NATIVE_VS_MANIFEST` (+ `STACK.GERBER_PARITY` with `artifacts.gerber_dir`) |
| `via_mask.design_target_mm`, `via_mask.process.limit_mm`, `via_mask.pad_contact` | the four `VIA.*` gates |
| `routing.permitted_turn_degrees`, `routing.min_segment_mm`, `routing.hygiene` | the three `ROUTE.*` gates |
| `net_topology.rules` | `NET.TOPOLOGY` |
| `connector_contracts` + `connector_gender_tokens` | `CONTRACT.CONNECTOR` |
| `placement_rules` | `CONTRACT.PLACEMENT` |
| `artifacts.bom` + `artifacts.cpl` | `BOM.NATIVE_PARITY` |
| `archive.zip` + `archive.allow` | `ARCH.CONTENTS` |
| `archive.manifest` | `ARCH.PROVENANCE` |
| `constraint_parity.rival_scan` | `CFG.NO_RIVAL_THRESHOLDS` |

`CFG.THRESHOLD_PARITY` always runs last and proves every limit any gate applied
resolves to the manifest key it cited.

### Rule types

`NetTopologyRule` measures true electrical path length through the copper graph
(tracks + vias) from a driver pad pattern to load pad patterns:

```json
{ "id": "CLK", "net_regex": "^CLK_B\\d+$", "source_pad_regex": "^R\\d+\\.2$",
  "load_pad_regex": "^U\\d+\\.3$", "max_spread_mm": 5.0,
  "max_vias_per_net": 0, "permitted_layers": ["F.Cu"] }
```

`ConnectorContractRule` checks positions, rows, pitch, side, DNP/BOM state,
pin-to-net map, gender agreement across footprint id / 3D model / description /
value, and documentation consistency (`must_claim` / `must_not_claim`).

`PlacementRule` checks polar radius, azimuth grid and radial rotation for a
family of references, with an optional local offset so a feature (an acoustic
port, say) can be measured instead of the footprint origin.

## Export parity, per object

Neither export gate compares totals.

`VIA.NATIVE_GERBER_AGREEMENT` matches **every** via individually. For each one
it finds the plated drill hit at that coordinate, the circular copper flash of
the right diameter on each outer layer, and then recomputes the whole mask
classification from Gerber geometry alone. Native and export must agree on:
signed clearance, contact, positive-area overlap, centre-inside, the project
limit class, the process limit class, and the identity of the nearest opening.
Identity is compared against the *tie set* - every opening as close as the
nearest to within `clearance_match_mm` - because a via sitting exactly between
two pads has no single nearest opening and two implementations may legitimately
pick different members.

`STACK.GERBER_PARITY` re-exports the native board with the flags recorded in
`artifacts.gerber_export_flags` and compares each shipped copper layer against
the fresh one by **geometric symmetric difference**, limited by
`layer_symmetric_difference_mm2`. Matching X2 file functions and non-empty
payloads are necessary but nowhere near sufficient.

Two mutation tests keep them honest:

- a solder-mask opening is relocated so one via loses its clearance, chosen so
  the count of via centres inside an opening is provably unchanged - the number
  the old totals-only gate compared. The per-object gate fails; a counting gate
  would not have noticed.
- a via is moved in the board without re-exporting, and object matching fails
  on the missing drill hit.
- one flash in a shipped copper Gerber is turned into a move, and per-layer
  symmetric difference fails.

## Measurement definitions

Via-to-mask distances are never collapsed into one number. Each via reports:

| Field | Meaning |
|---|---|
| `drill_to_opening_mm` | hole edge to mask aperture edge |
| `annulus_to_opening_mm` | via pad edge to mask aperture edge (the process metric) |
| `centre_to_opening_mm` | via centre to aperture edge, negative when inside |
| `annulus_to_pad_copper_mm` | via pad edge to pad copper edge |
| `annulus_contacts_opening` | separation at or below `geometry_profile.tolerances.contact_mm` |
| `annulus_overlaps_opening` | positive shared area only |

Curved shapes are polygonised **outward** at 1 µm chord error, so an
approximation can only under-state clearance, never over-state it. The
synthetic tests assert that directly.

Contact is a tolerance decision, not an exact predicate: two independent
polygonisations of the same tangency can differ by a sub-nanometre gap, so
anything at or below `contact_mm` (1e-6 mm) counts as contact and is treated
per the configured `via_mask.mask_dam_rule`. Positive-area overlap is reported
separately, so a tangency is never silently folded into an overlap count.

## Fail-closed behaviour

- An unknown Gerber aperture, macro primitive or open region raises rather than
  being skipped. (Silently skipping macro apertures is precisely how an earlier
  manual review missed a via-in-pad population.)
- A gate that throws is reported `ERROR` and blocks the release.
- A missing manifest key raises; there are no defaults.
- Board default via tenting that cannot be resolved raises.

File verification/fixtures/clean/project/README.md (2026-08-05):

# clean - a deliberately boring positive fixture

Rev A is a permanent *negative* fixture: it must be rejected. That makes it
useless for proving the opposite property - that a check which passes is
capable of failing. A gate that always fails and a gate that always passes look
identical when you only ever point them at a board that should fail.

This project is the positive control. It is a 20 mm square outline, an empty
schematic, and a project file that leaves no rule disabled. It has no
components on purpose: schematic-parity would otherwise report a footprint with
no symbol, and the point here is a board with nothing whatsoever to report.

    ERC  exit 0, 0 violations, 0 ignored checks
    DRC  exit 0, 0 violations, 0 unconnected items, 0 parity issues,
         0 ignored checks

Tests mutate a *copy* of it to produce a real finding and assert the gate turns
from PASS to FAIL. Keep it clean; if a KiCad upgrade makes it report something,
that is a finding about the upgrade and belongs in the test output, not in a
quiet edit to this fixture.

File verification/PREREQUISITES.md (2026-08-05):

# Prerequisites

This framework runs inside **KiCad's own Python**. That is a deliberate choice,
not a limitation to be worked around: the checks read the design through
`pcbnew`, which is a SWIG binding compiled against the KiCad build it ships
with. A `pcbnew` from one KiCad and a `kicad-cli` from another do not agree
about geometry, and there is no version of this framework that can make them.

Run everything as:

```bash
"C:/Program Files/KiCad/10.0/bin/python.exe" verification/run.py preflight
```

## What must already be present

| Component | Supplied by | How it is obtained |
|---|---|---|
| Python ≥ 3.11 | KiCad | ships inside the KiCad installation |
| `pcbnew` | KiCad | ships inside the KiCad installation |
| `kicad-cli` | KiCad | ships inside the KiCad installation; path from the board manifest's `tools.kicad_cli` |
| Shapely | a KiCad add-on | KiCad's **Plugin and Content Manager** |

Everything else the framework uses is in the Python standard library. There is
no `requirements.txt`, no virtual environment and no lockfile, because there is
no environment here that this project owns.

## What this framework will never do

**It will not install, upgrade, downgrade or pin anything.** Shapely in
particular is provided by an installed KiCad add-on and is therefore owned by
that environment. Pinning it here — even to the version that happens to be
present — would mean this project quietly fighting the add-on manager over a
shared installation, and the first `pip install` that "fixed" a version would
be the one that broke somebody's KiCad.

If a prerequisite is missing or unusable, `run.py preflight` says so, names the
component, prints where it looked, and exits nonzero. It then stops.

## How compatibility is actually decided

Not by comparing version strings. `preflight` probes the specific APIs and
behaviours the checks rely on:

- `pcbnew`: `BOARD.Tracks`, `PCB_VIA.GetWidth(layer)`,
  `PAD.TransformShapeToPolygon`, `ERROR_OUTSIDE`, `TENTING_MODE_TENTED`,
  `FOOTPRINT.GetFPIDAsString`
- Shapely: edge-touching polygons must report `distance() == 0` and zero
  intersection area, `buffer()` must grow a polygon, and `STRtree.query` must
  work
- `kicad-cli`: must answer `--version`

A build that passes those probes is usable whatever it calls itself; a build
that fails one is rejected with the failing probe named, whatever its version
number says.

### Version ranges that genuinely matter

- **KiCad 10.0.x** — the ERC and DRC JSON report *schemas* are version-specific.
  KiCad 10 puts DRC findings under a top-level `violations` key and ERC findings
  under `sheets[].violations`. `pcbqa/reports.py` implements that schema and
  raises `ReportSchemaError` rather than guessing at another one, so a report
  from a different major version is reported as unsupported, not
  misinterpreted.
- **Python ≥ 3.11** — the language features the framework uses.
- **Shapely 2.x** — `STRtree.query` returns indices in 2.x and geometries in
  1.x. The predicate probe catches the difference.

Every validation and release report records the resolved version **and the
module path** of each component under `tooling.components`, so a result can
always be traced back to the environment that produced it.

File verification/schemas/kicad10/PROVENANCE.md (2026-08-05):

# Vendored KiCad 10 report schemas

Retrieved 2026-08-04 from the addresses the reports themselves declare in their
`$schema` field:

| File | Source | sha256 |
|---|---|---|
| `drc.v1.json` | `https://schemas.kicad.org/drc.v1.json` | `4699a2ecde9f3d1341187fa6805991a08c385fb6e44c17b0a5c74441886d8e9c` |
| `erc.v1.json` | `https://schemas.kicad.org/erc.v1.json` | `b8637f15b60138685c68b8c6a0b5357657162bd3a06d361b801d955ac2ab1690` |

They are stored **byte-for-byte as retrieved**, so the digests above can be
checked against the upstream files at any time. They are vendored rather than
fetched at validation time for the obvious reason: a checker that needs the
network to decide whether a board is manufacturable will one day decide it is,
because the network was down and someone added a fallback.

## Upstream defect: `drc.v1.json` is not valid JSON

The DRC schema has a trailing comma in its top-level `required` array:

```json
  "required": [
    "source",
    "date",
    "kicad_version",
    "violations",
    "unconnected_items",
    "schematic_parity",
    "coordinate_units",
  ],
```

`json.loads` rejects this at line 93. The file has been left exactly as
published; `pcbqa.schema.load_schema` strips trailing commas before parsing and
records that it had to. Correcting the vendored copy would have made the
digests above unverifiable against upstream, which is a worse trade than
tolerating one comma in a loader that says out loud what it is tolerating.

The ERC schema parses cleanly.

## Two things the schemas say that are worth knowing

**`severity` is `["error", "warning"]` only.** "exclusion" appears in
`included_severities` — it is a severity you can *ask for* — but a violation
carries `excluded: true` rather than a severity of "exclusion". A checker that
looked for `severity == "exclusion"` would never find one.

**ERC does not require `coordinate_units`; DRC does.** Both schemas allow
`mm`, `mils` and `in`. Coordinates are therefore not millimetres until
something converts them, which is why `pcbqa.reports` converts to millimetres
at parse time and stores nothing in the units it was handed.

`included_severities` and `ignored_checks` are optional in both schemas. This
validator requires them anyway: a report that does not say which severities it
included cannot be evidence that anything was checked. That requirement is the
validator's, is applied after schema validation, and says so in its message.

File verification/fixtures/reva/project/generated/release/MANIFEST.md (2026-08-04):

# Release candidate manifest

- `microphone_array_v2-revA-fabrication.zip` sha256 `a3c4c5d2b3282c06cc37fce987b2dd4712548ae0ec38ea4efc484124e038fa3d`
- `microphone_array_v2.kicad_pcb` sha256 `b5606e1cead80d406902a7e7a82f0e2220bcef1da916c8662e846c76b265bb27`
- `bom.csv` sha256 `8dbdc7dc144a9dffc79b9d3d06bb52761a83d726b0eb459fba376d300e39e8a1`
- `cpl.csv` sha256 `b4d02eac068c4f017d7f744862a78557474bd3200bfd94f4598278290d7ab48f`
- `positions.csv` sha256 `305e391553aad2e0ea7647e4b7571495a5777fe80d91dce5947bfa2ee623b964`

This is a release candidate. Before ordering, inspect JLCPCB's live
Gerber and pick-and-place previews and confirm every component match
and placement orientation. Local renders cannot prove JLCPCB's
library-model zero orientation.

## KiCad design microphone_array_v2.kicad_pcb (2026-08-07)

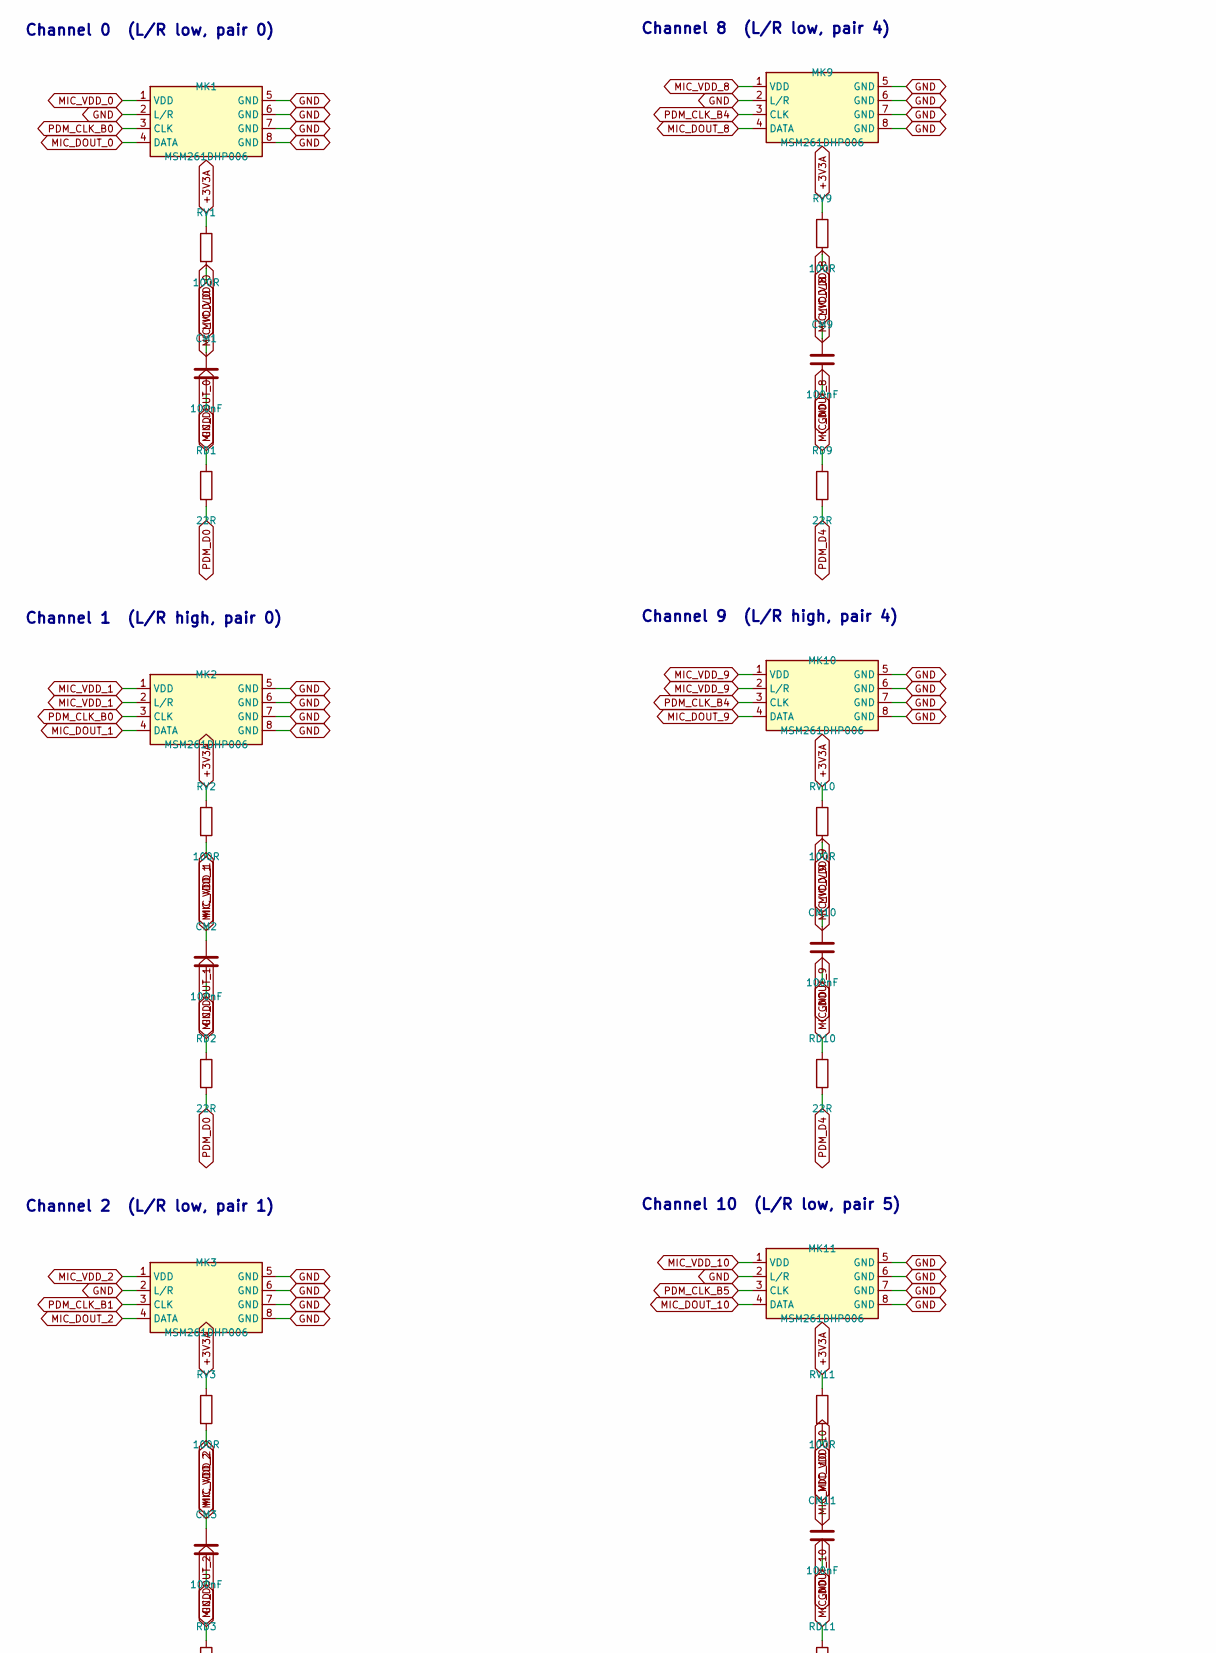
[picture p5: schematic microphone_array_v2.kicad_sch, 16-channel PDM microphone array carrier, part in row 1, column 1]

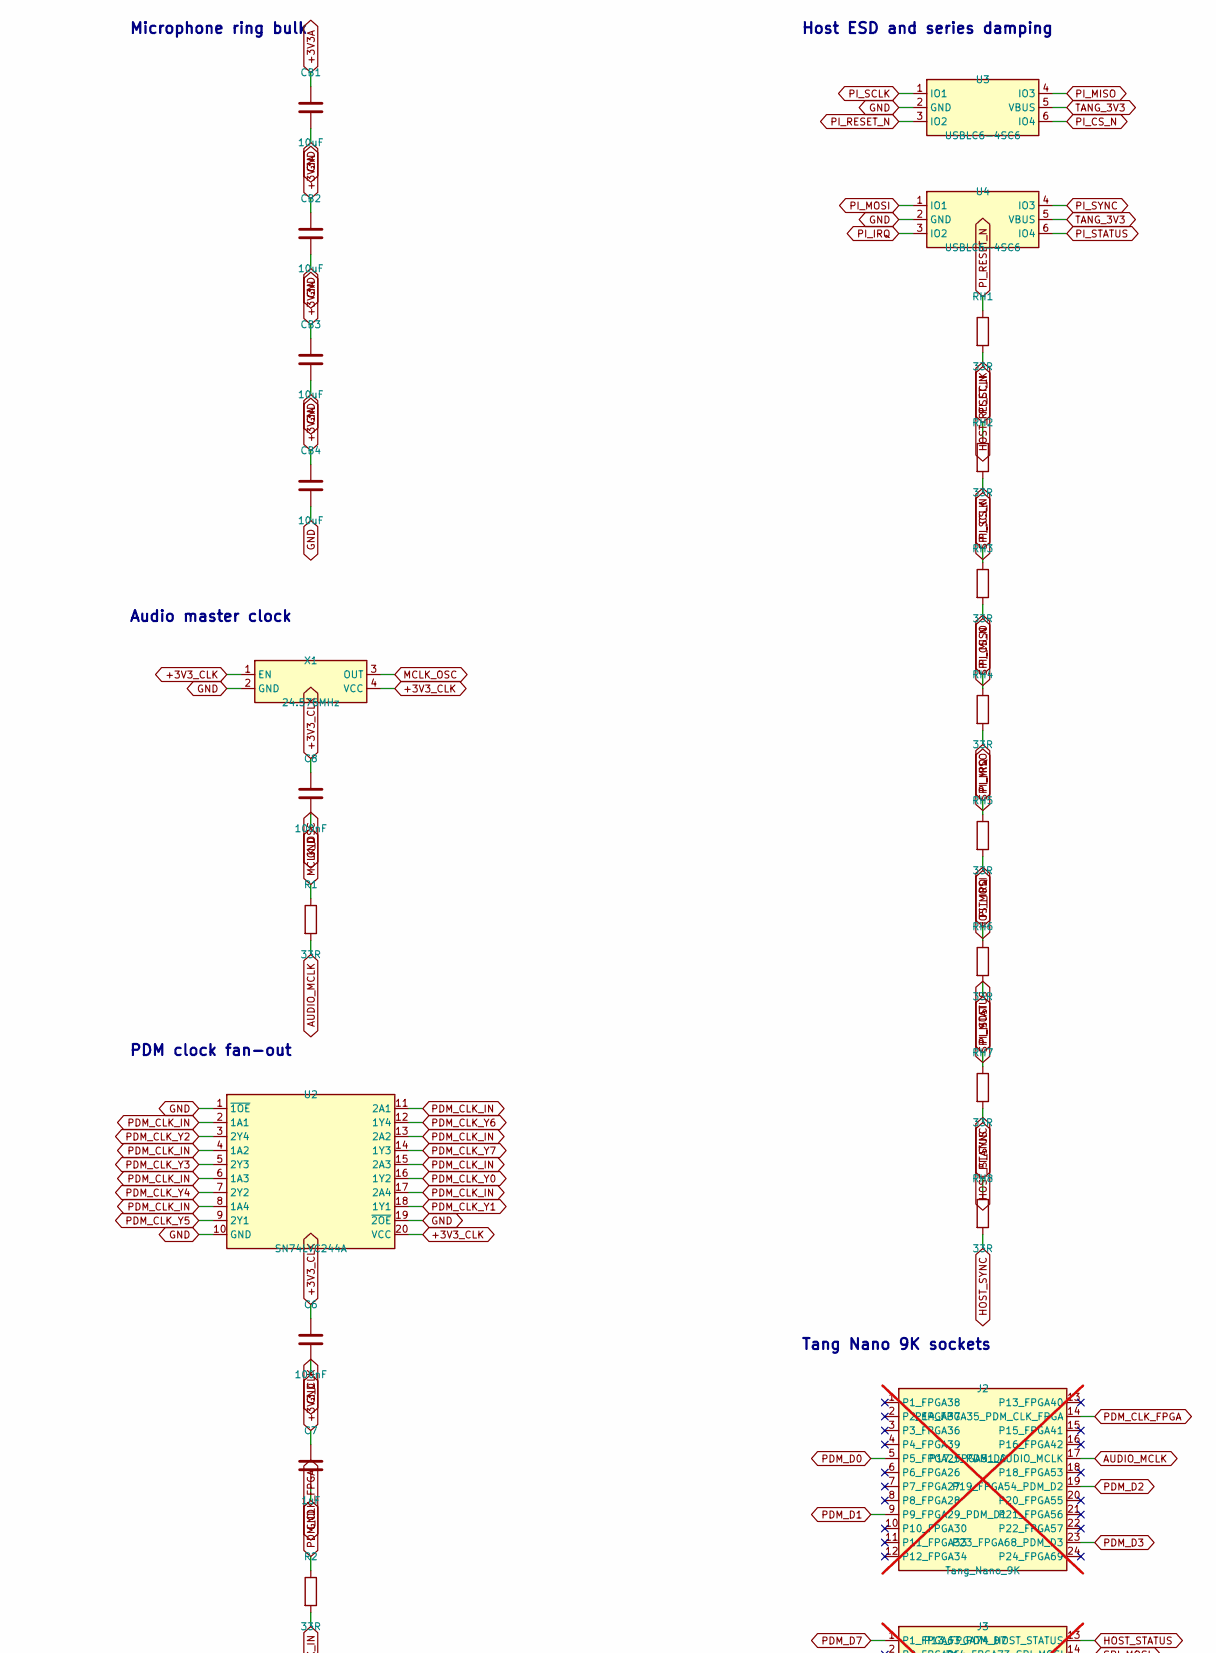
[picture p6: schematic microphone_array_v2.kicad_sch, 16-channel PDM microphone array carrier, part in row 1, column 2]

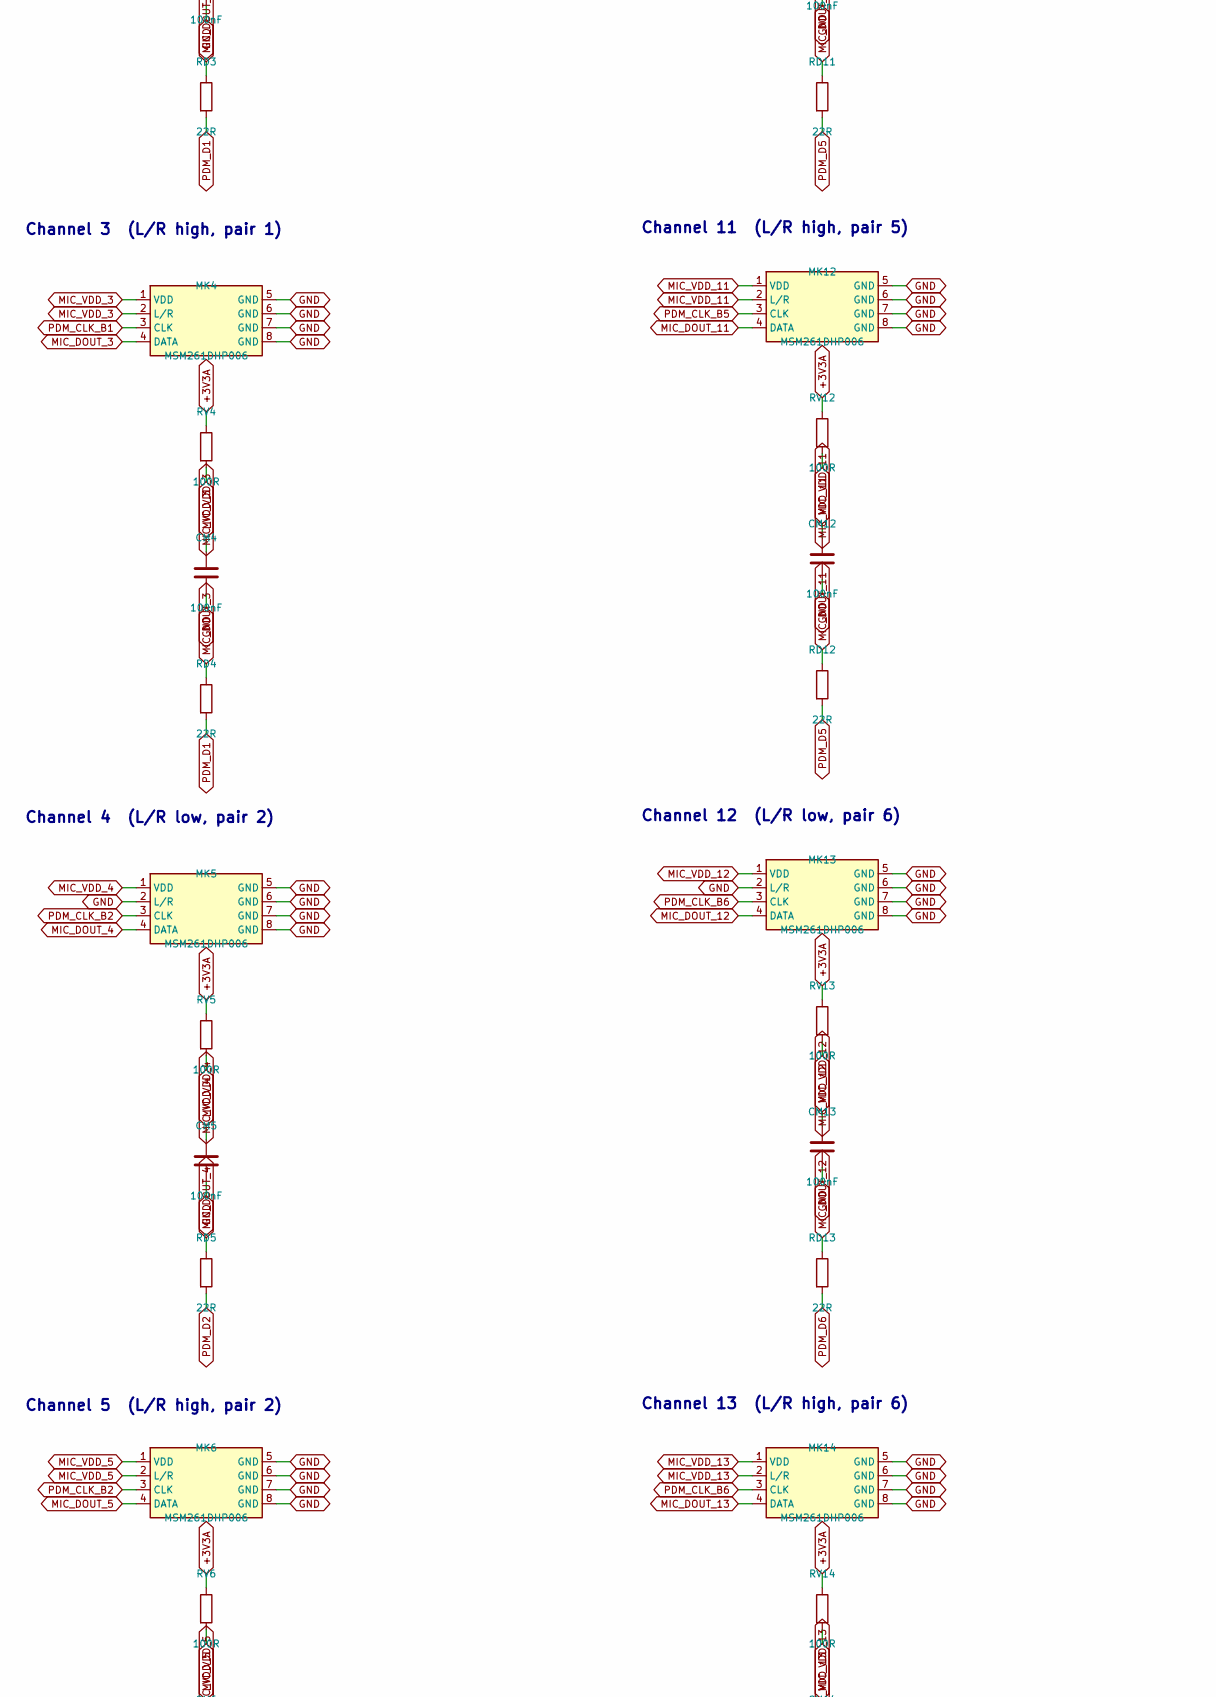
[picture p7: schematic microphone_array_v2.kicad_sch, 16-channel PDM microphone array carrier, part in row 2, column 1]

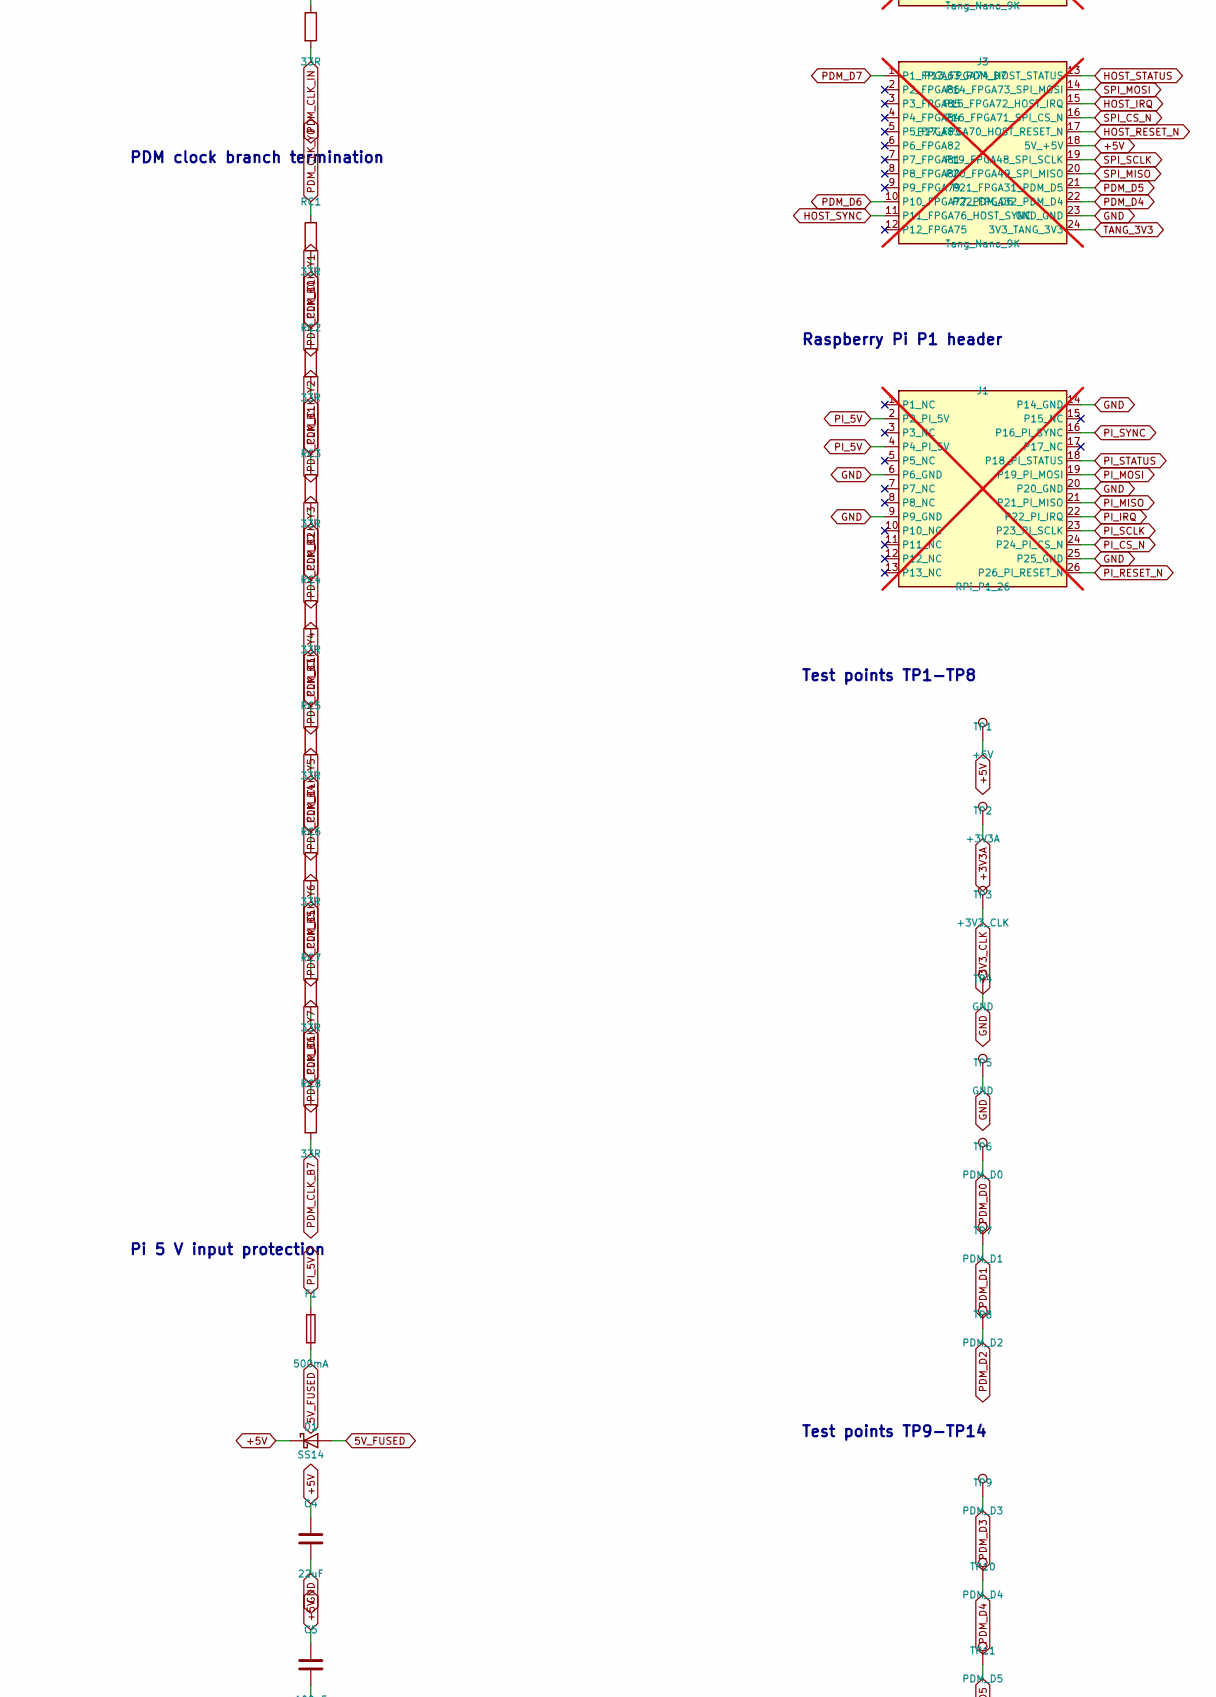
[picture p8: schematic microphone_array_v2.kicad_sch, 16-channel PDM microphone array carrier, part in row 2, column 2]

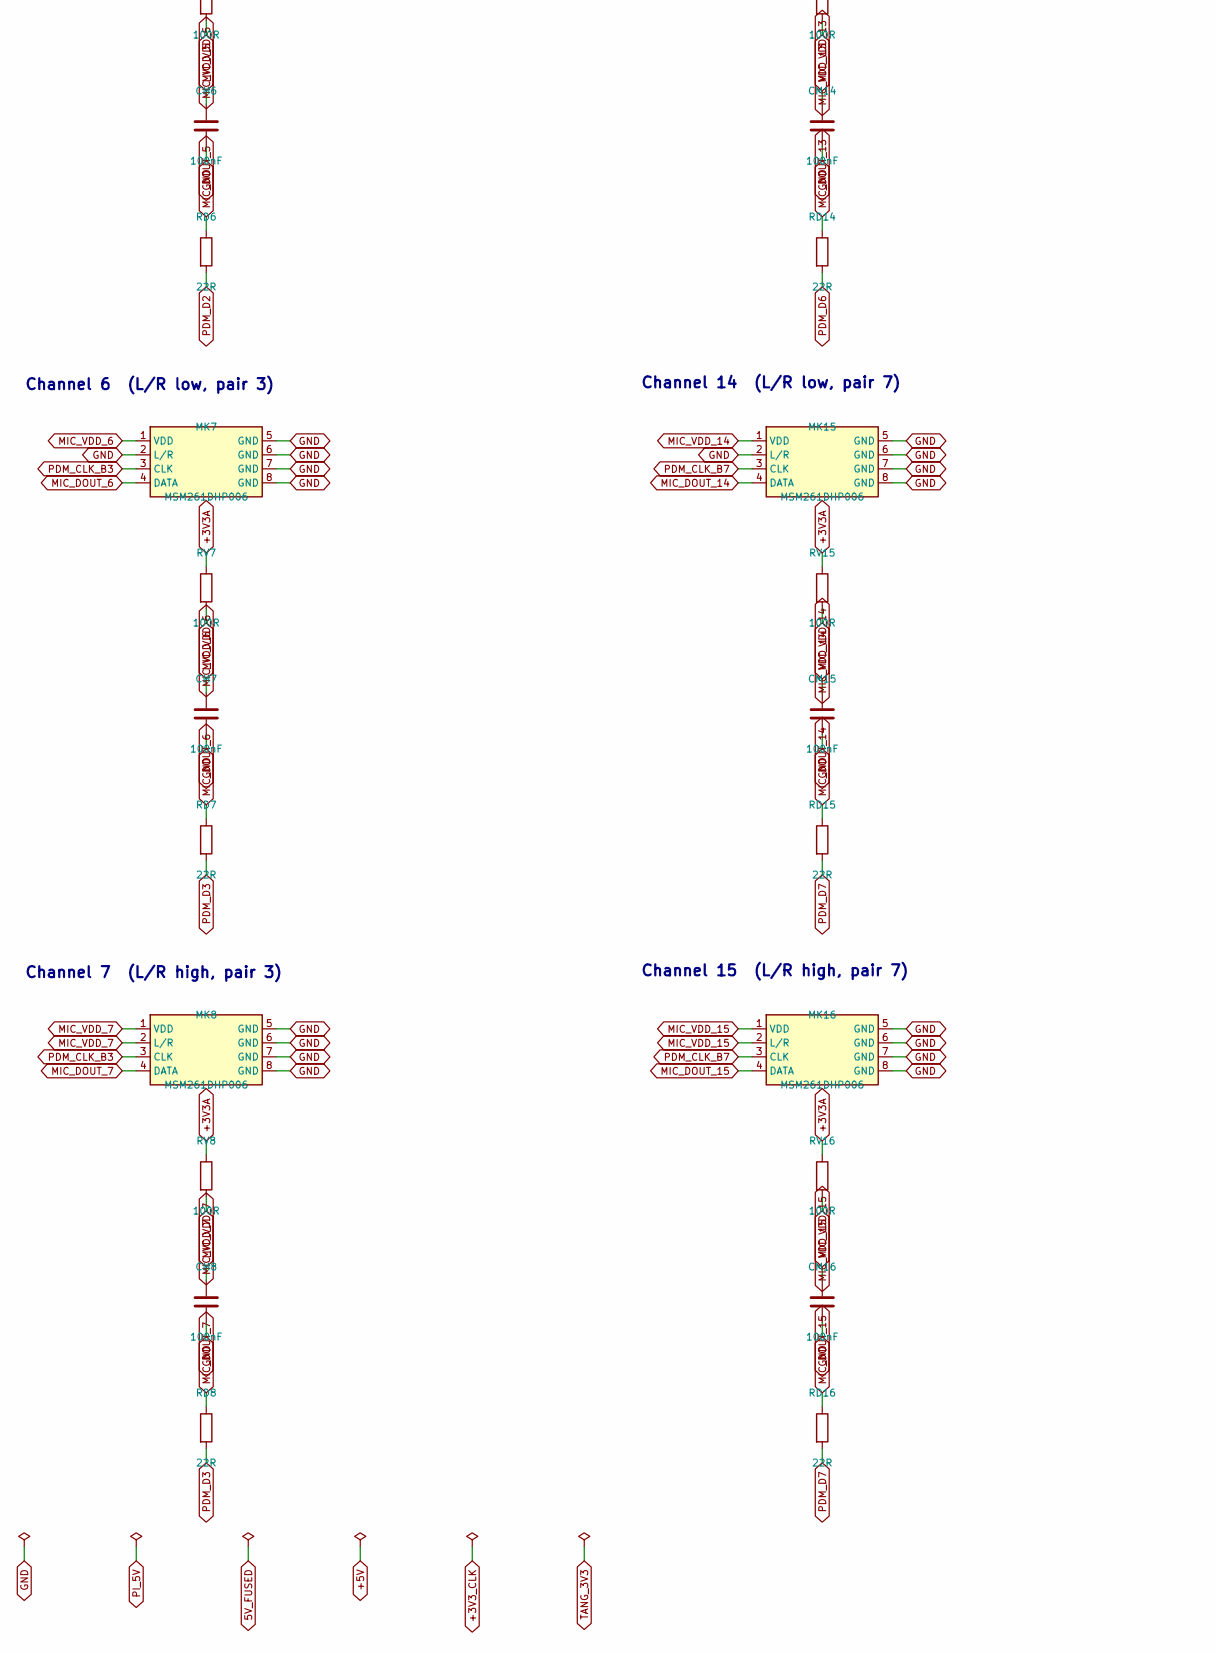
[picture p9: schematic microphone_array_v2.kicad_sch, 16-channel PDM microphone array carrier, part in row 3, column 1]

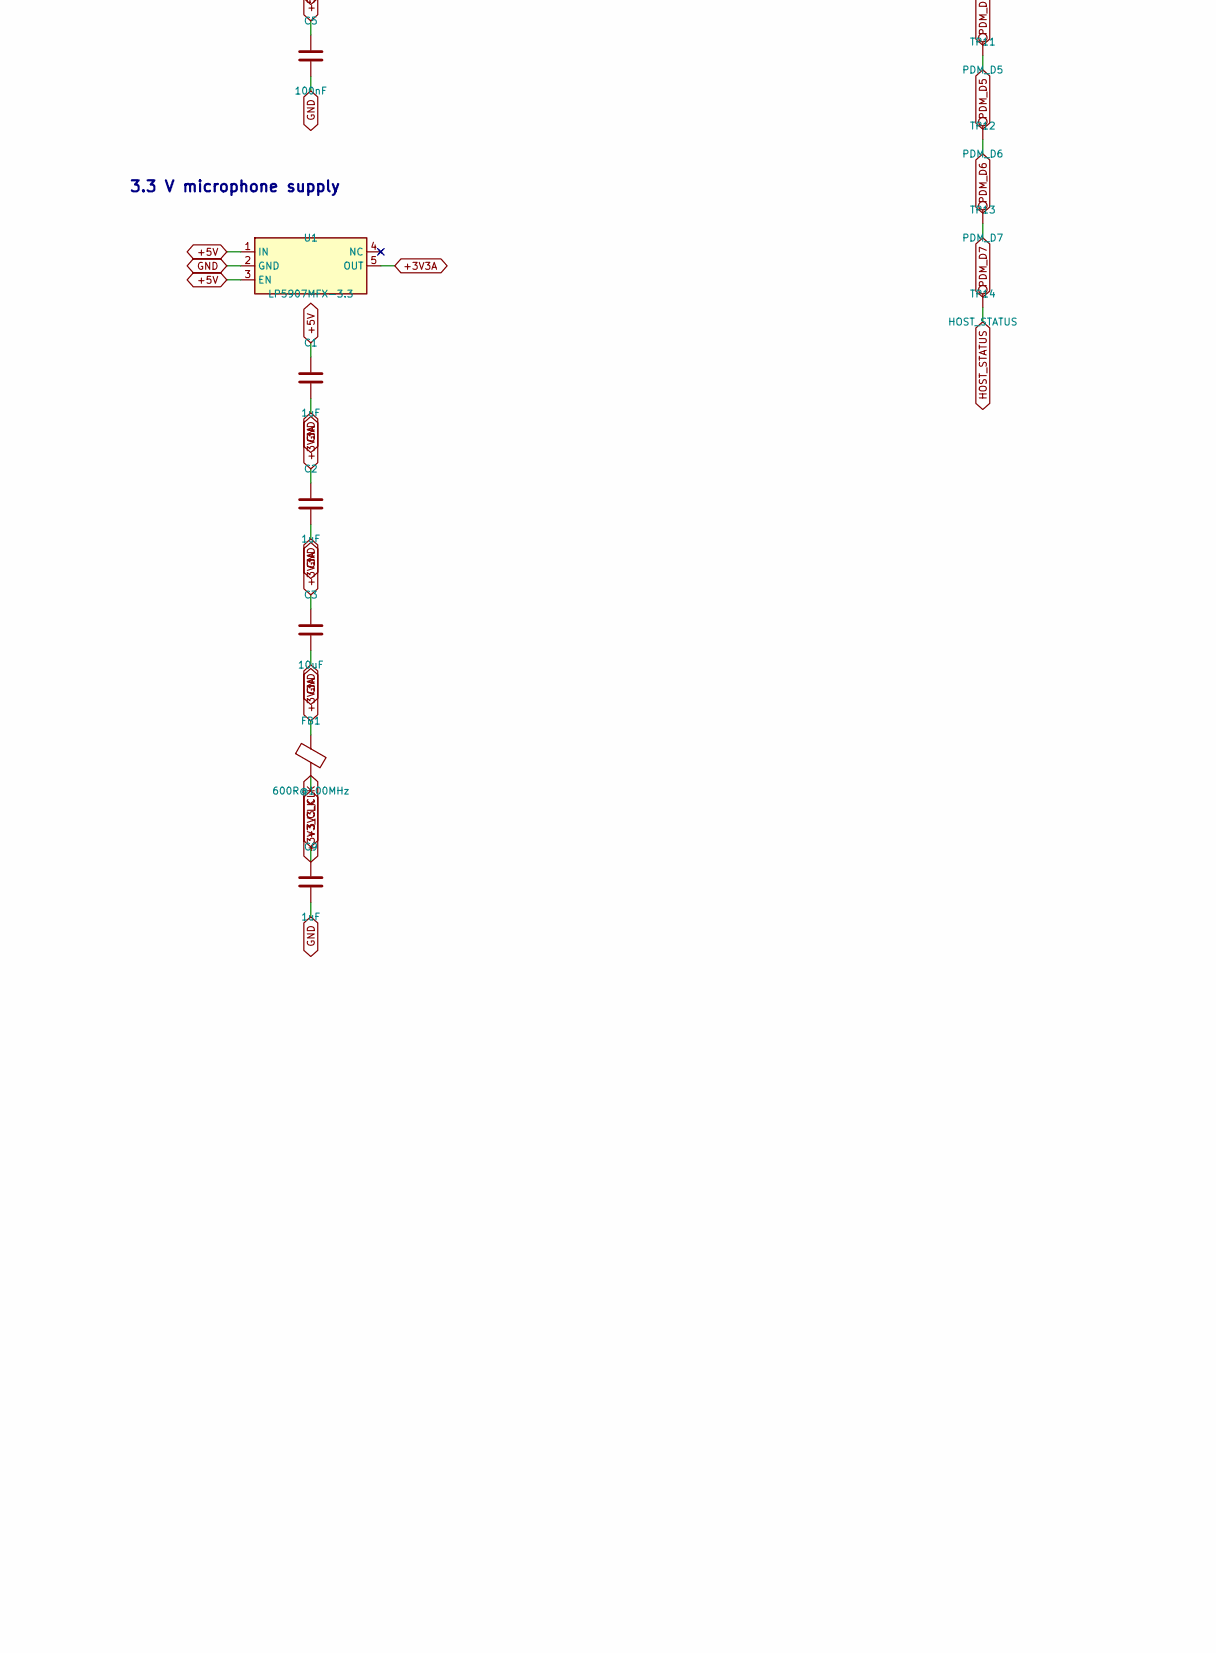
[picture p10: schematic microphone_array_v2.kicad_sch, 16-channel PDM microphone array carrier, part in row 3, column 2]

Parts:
C1, C2, C7, C9: 1uF; C_0603_1608Metric; MPN CC0603KRX7R8BB105; LCSC C106858
C3: 10uF; C_0805_2012Metric; MPN CL21A106KAYNNNE; LCSC C15850
C4: 22uF; C_0805_2012Metric; MPN C2012X5R1C226KT000E; LCSC C76637
C5, C6, C8: 100nF; C_0402_1005Metric; MPN CL05B104KO5NNNC; LCSC C1525
CB1, CB2, CB3, CB4: 10uF; C_0805_2012Metric; MPN CL21A106KAYNNNE; LCSC C15850
CM1, CM2, CM3, CM4, CM5, CM6, CM7, CM8, CM9, CM10, CM11, CM12, CM13, CM14, CM15, CM16: 100nF; C_0402_1005Metric; MPN CL05B104KO5NNNC; LCSC C1525
D1: SS14; D_SMA; MPN SS14; LCSC C2480
F1: 500mA; Fuse_1812_4532Metric; MPN JK-MSMD050-30; LCSC C369168
FB1: 600R@100MHz; L_0805_2012Metric; MPN GZ2012D601TF; LCSC C1017
J1: RPi_P1_26; PinSocket_2x13_P2.54mm_Vertical; not fitted
J2, J3: Tang_Nano_9K; PinHeader_1x24_P2.54mm_Vertical; not fitted
MK1, MK2, MK3, MK4, MK5, MK6, MK7, MK8, MK9, MK10, MK11, MK12, MK13, MK14, MK15, MK16: MSM261DHP006; MSM261DHP006_LGA-8_3x4mm_TopPort; MPN MSM261DHP006; LCSC C22390138
R1, R2: 33R; R_0402_1005Metric; MPN 0402WGF330JTCE; LCSC C25105
RC1, RC2, RC3, RC4, RC5, RC6, RC7, RC8: 33R; R_0402_1005Metric; MPN 0402WGF330JTCE; LCSC C25105
RD1, RD2, RD3, RD4, RD5, RD6, RD7, RD8, RD9, RD10, RD11, RD12, RD13, RD14, RD15, RD16: 22R; R_0402_1005Metric; MPN 0402WGF220JTCE; LCSC C25092
RH1, RH2, RH3, RH4, RH5, RH6, RH7, RH8: 33R; R_0402_1005Metric; MPN 0402WGF330JTCE; LCSC C25105
RV1, RV2, RV3, RV4, RV5, RV6, RV7, RV8, RV9, RV10, RV11, RV12, RV13, RV14, RV15, RV16: 100R; R_0402_1005Metric; MPN 0402WGF1000TCE; LCSC C25076
TP1: +5V; TestPoint_Pad_D1.0mm_NoSilk
TP2: +3V3A; TestPoint_Pad_D1.5mm_NoSilk
TP3: +3V3_CLK; TestPoint_Pad_D1.5mm_NoSilk
TP4, TP5: GND; TestPoint_Pad_D1.5mm_NoSilk
TP6: PDM_D0; TestPoint_Pad_D1.5mm_NoSilk
TP7: PDM_D1; TestPoint_Pad_D1.5mm_NoSilk
TP8: PDM_D2; TestPoint_Pad_D1.5mm_NoSilk
TP9: PDM_D3; TestPoint_Pad_D1.5mm_NoSilk
TP10: PDM_D4; TestPoint_Pad_D1.5mm_NoSilk
TP11: PDM_D5; TestPoint_Pad_D1.5mm_NoSilk
TP12: PDM_D6; TestPoint_Pad_D1.5mm_NoSilk
TP13: PDM_D7; TestPoint_Pad_D1.5mm_NoSilk
TP14: HOST_STATUS; TestPoint_Pad_D1.0mm_NoSilk
U1: LP5907MFX-3.3; SOT-23-5; MPN LP5907MFX-3.3/NOPB; LCSC C80670
U2: SN74LVC244A; TSSOP-20_4.4x6.5mm_P0.65mm; MPN SN74LVC244APWR; LCSC C7668
U3, U4: USBLC6-4SC6; SOT-23-6; MPN USBLC6-4SC6; LCSC C111212
X1: 24.576MHz; Oscillator_SMD_YXC_3.2x2.5mm_4Pin; MPN OT322524.576MJBA4SL; LCSC C2831388

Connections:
5V_FUSED: D1.2 (A), F1.2
+3V3A: C2.1, C3.1, CB1.1, CB2.1, CB3.1, CB4.1, FB1.1, RV1.1, RV2.1, RV3.1, RV4.1, RV5.1, RV6.1, RV7.1, RV8.1, RV9.1, RV10.1, RV11.1, RV12.1, RV13.1, RV14.1, RV15.1, RV16.1, TP2.1, U1.5 (OUT)
+3V3_CLK: C6.1, C7.1, C8.1, C9.1, FB1.2, TP3.1, U2.20 (VCC), X1.1 (EN), X1.4 (VCC)
+5V: C1.1, C4.1, C5.1, D1.1 (K), J3.18 (5V_+5V), TP1.1, U1.1 (IN), U1.3 (EN)
AUDIO_MCLK: J2.17 (P17_FPGA51_AUDIO_MCLK), R1.2
GND: C1.2, C2.2, C3.2, C4.2, C5.2, C6.2, C7.2, C8.2, C9.2, CB1.2, CB2.2, CB3.2, CB4.2, CM1.2, CM2.2, CM3.2, CM4.2, CM5.2, CM6.2, CM7.2, CM8.2, CM9.2, CM10.2, CM11.2, CM12.2, CM13.2, CM14.2, CM15.2, CM16.2, J1.6 (P6_GND), J1.9 (P9_GND), J1.14 (P14_GND), J1.20 (P20_GND), J1.25 (P25_GND), J3.23 (GND_GND), MK1.2 (L/R), MK1.5 (GND), MK1.6 (GND), MK1.7 (GND), MK1.8 (GND), MK2.5 (GND), MK2.6 (GND), MK2.7 (GND), MK2.8 (GND), MK3.2 (L/R), MK3.5 (GND), MK3.6 (GND), MK3.7 (GND), MK3.8 (GND), MK4.5 (GND), MK4.6 (GND), MK4.7 (GND), MK4.8 (GND), MK5.2 (L/R), MK5.5 (GND), MK5.6 (GND), MK5.7 (GND), MK5.8 (GND), MK6.5 (GND), MK6.6 (GND), MK6.7 (GND), MK6.8 (GND), MK7.2 (L/R), MK7.5 (GND), MK7.6 (GND), MK7.7 (GND), MK7.8 (GND), MK8.5 (GND), MK8.6 (GND), MK8.7 (GND), MK8.8 (GND), MK9.2 (L/R), MK9.5 (GND), MK9.6 (GND), MK9.7 (GND), MK9.8 (GND), MK10.5 (GND), MK10.6 (GND), MK10.7 (GND), MK10.8 (GND), MK11.2 (L/R), MK11.5 (GND), MK11.6 (GND), MK11.7 (GND), MK11.8 (GND), MK12.5 (GND), MK12.6 (GND), MK12.7 (GND), MK12.8 (GND), MK13.2 (L/R), MK13.5 (GND), MK13.6 (GND), MK13.7 (GND), MK13.8 (GND), MK14.5 (GND), MK14.6 (GND), MK14.7 (GND), MK14.8 (GND), MK15.2 (L/R), MK15.5 (GND), MK15.6 (GND), MK15.7 (GND), MK15.8 (GND), MK16.5 (GND), MK16.6 (GND), MK16.7 (GND), MK16.8 (GND), TP4.1, TP5.1, U1.2 (GND), U2.1 (~1OE), U2.10 (GND), U2.19 (~2OE), U3.2 (GND), U4.2 (GND), X1.2 (GND)
HOST_IRQ: J3.15 (P15_FPGA72_HOST_IRQ), RH5.2
HOST_RESET_N: J3.17 (P17_FPGA70_HOST_RESET_N), RH1.2
HOST_STATUS: J3.13 (P13_FPGA74_HOST_STATUS), RH7.2, TP14.1
HOST_SYNC: J3.11 (P11_FPGA76_HOST_SYNC), RH8.2
MCLK_OSC: R1.1, X1.3 (OUT)
MIC_DOUT_0: MK1.4 (DATA), RD1.1
MIC_DOUT_1: MK2.4 (DATA), RD2.1
MIC_DOUT_2: MK3.4 (DATA), RD3.1
MIC_DOUT_3: MK4.4 (DATA), RD4.1
MIC_DOUT_4: MK5.4 (DATA), RD5.1
MIC_DOUT_5: MK6.4 (DATA), RD6.1
MIC_DOUT_6: MK7.4 (DATA), RD7.1
MIC_DOUT_7: MK8.4 (DATA), RD8.1
MIC_DOUT_8: MK9.4 (DATA), RD9.1
MIC_DOUT_9: MK10.4 (DATA), RD10.1
MIC_DOUT_10: MK11.4 (DATA), RD11.1
MIC_DOUT_11: MK12.4 (DATA), RD12.1
MIC_DOUT_12: MK13.4 (DATA), RD13.1
MIC_DOUT_13: MK14.4 (DATA), RD14.1
MIC_DOUT_14: MK15.4 (DATA), RD15.1
MIC_DOUT_15: MK16.4 (DATA), RD16.1
MIC_VDD_0: CM1.1, MK1.1 (VDD), RV1.2
MIC_VDD_1: CM2.1, MK2.1 (VDD), MK2.2 (L/R), RV2.2
MIC_VDD_2: CM3.1, MK3.1 (VDD), RV3.2
MIC_VDD_3: CM4.1, MK4.1 (VDD), MK4.2 (L/R), RV4.2
MIC_VDD_4: CM5.1, MK5.1 (VDD), RV5.2
MIC_VDD_5: CM6.1, MK6.1 (VDD), MK6.2 (L/R), RV6.2
MIC_VDD_6: CM7.1, MK7.1 (VDD), RV7.2
MIC_VDD_7: CM8.1, MK8.1 (VDD), MK8.2 (L/R), RV8.2
MIC_VDD_8: CM9.1, MK9.1 (VDD), RV9.2
MIC_VDD_9: CM10.1, MK10.1 (VDD), MK10.2 (L/R), RV10.2
MIC_VDD_10: CM11.1, MK11.1 (VDD), RV11.2
MIC_VDD_11: CM12.1, MK12.1 (VDD), MK12.2 (L/R), RV12.2
MIC_VDD_12: CM13.1, MK13.1 (VDD), RV13.2
MIC_VDD_13: CM14.1, MK14.1 (VDD), MK14.2 (L/R), RV14.2
MIC_VDD_14: CM15.1, MK15.1 (VDD), RV15.2
MIC_VDD_15: CM16.1, MK16.1 (VDD), MK16.2 (L/R), RV16.2
PDM_CLK_B0: MK1.3 (CLK), MK2.3 (CLK), RC1.2
PDM_CLK_B1: MK3.3 (CLK), MK4.3 (CLK), RC2.2
PDM_CLK_B2: MK5.3 (CLK), MK6.3 (CLK), RC3.2
PDM_CLK_B3: MK7.3 (CLK), MK8.3 (CLK), RC4.2
PDM_CLK_B4: MK9.3 (CLK), MK10.3 (CLK), RC5.2
PDM_CLK_B5: MK11.3 (CLK), MK12.3 (CLK), RC6.2
PDM_CLK_B6: MK13.3 (CLK), MK14.3 (CLK), RC7.2
PDM_CLK_B7: MK15.3 (CLK), MK16.3 (CLK), RC8.2
PDM_CLK_FPGA: J2.14 (P14_FPGA35_PDM_CLK_FPGA), R2.1
PDM_CLK_IN: R2.2, U2.2 (1A1), U2.4 (1A2), U2.6 (1A3), U2.8 (1A4), U2.11 (2A1), U2.13 (2A2), U2.15 (2A3), U2.17 (2A4)
PDM_CLK_Y0: RC1.1, U2.16 (1Y2)
PDM_CLK_Y1: RC2.1, U2.18 (1Y1)
PDM_CLK_Y2: RC3.1, U2.3 (2Y4)
PDM_CLK_Y3: RC4.1, U2.5 (2Y3)
PDM_CLK_Y4: RC5.1, U2.7 (2Y2)
PDM_CLK_Y5: RC6.1, U2.9 (2Y1)
PDM_CLK_Y6: RC7.1, U2.12 (1Y4)
PDM_CLK_Y7: RC8.1, U2.14 (1Y3)
PDM_D0: J2.5 (P5_FPGA25_PDM_D0), RD1.2, RD2.2, TP6.1
PDM_D1: J2.9 (P9_FPGA29_PDM_D1), RD3.2, RD4.2, TP7.1
PDM_D2: J2.19 (P19_FPGA54_PDM_D2), RD5.2, RD6.2, TP8.1
PDM_D3: J2.23 (P23_FPGA68_PDM_D3), RD7.2, RD8.2, TP9.1
PDM_D4: J3.22 (P22_FPGA32_PDM_D4), RD9.2, RD10.2, TP10.1
PDM_D5: J3.21 (P21_FPGA31_PDM_D5), RD11.2, RD12.2, TP11.1
PDM_D6: J3.10 (P10_FPGA77_PDM_D6), RD13.2, RD14.2, TP12.1
PDM_D7: J3.1 (P1_FPGA63_PDM_D7), RD15.2, RD16.2, TP13.1
PI_5V: F1.1, J1.2 (P2_PI_5V), J1.4 (P4_PI_5V)
PI_CS_N: J1.24 (P24_PI_CS_N), RH3.1, U3.6 (IO4)
PI_IRQ: J1.22 (P22_PI_IRQ), RH5.1, U4.3 (IO2)
PI_MISO: J1.21 (P21_PI_MISO), RH4.1, U3.4 (IO3)
PI_MOSI: J1.19 (P19_PI_MOSI), RH6.1, U4.1 (IO1)
PI_RESET_N: J1.26 (P26_PI_RESET_N), RH1.1, U3.3 (IO2)
PI_SCLK: J1.23 (P23_PI_SCLK), RH2.1, U3.1 (IO1)
PI_STATUS: J1.18 (P18_PI_STATUS), RH7.1, U4.6 (IO4)
PI_SYNC: J1.16 (P16_PI_SYNC), RH8.1, U4.4 (IO3)
SPI_CS_N: J3.16 (P16_FPGA71_SPI_CS_N), RH3.2
SPI_MISO: J3.20 (P20_FPGA49_SPI_MISO), RH4.2
SPI_MOSI: J3.14 (P14_FPGA73_SPI_MOSI), RH6.2
SPI_SCLK: J3.19 (P19_FPGA48_SPI_SCLK), RH2.2
TANG_3V3: J3.24 (3V3_TANG_3V3), U3.5 (VBUS), U4.5 (VBUS)

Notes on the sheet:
Channel 0 (L/R low, pair 0)
Channel 1 (L/R high, pair 0)
Channel 2 (L/R low, pair 1)
Channel 3 (L/R high, pair 1)
Channel 4 (L/R low, pair 2)
Channel 5 (L/R high, pair 2)
Channel 6 (L/R low, pair 3)
Channel 7 (L/R high, pair 3)
Channel 8 (L/R low, pair 4)
Channel 9 (L/R high, pair 4)
Channel 10 (L/R low, pair 5)
Channel 11 (L/R high, pair 5)
Channel 12 (L/R low, pair 6)
Channel 13 (L/R high, pair 6)
Channel 14 (L/R low, pair 7)
Channel 15 (L/R high, pair 7)
Microphone ring bulk
Audio master clock
PDM clock fan-out
PDM clock branch termination
Pi 5 V input protection
3.3 V microphone supply
Host ESD and series damping
Tang Nano 9K sockets
Raspberry Pi P1 header
Test points TP1-TP8
Test points TP9-TP14

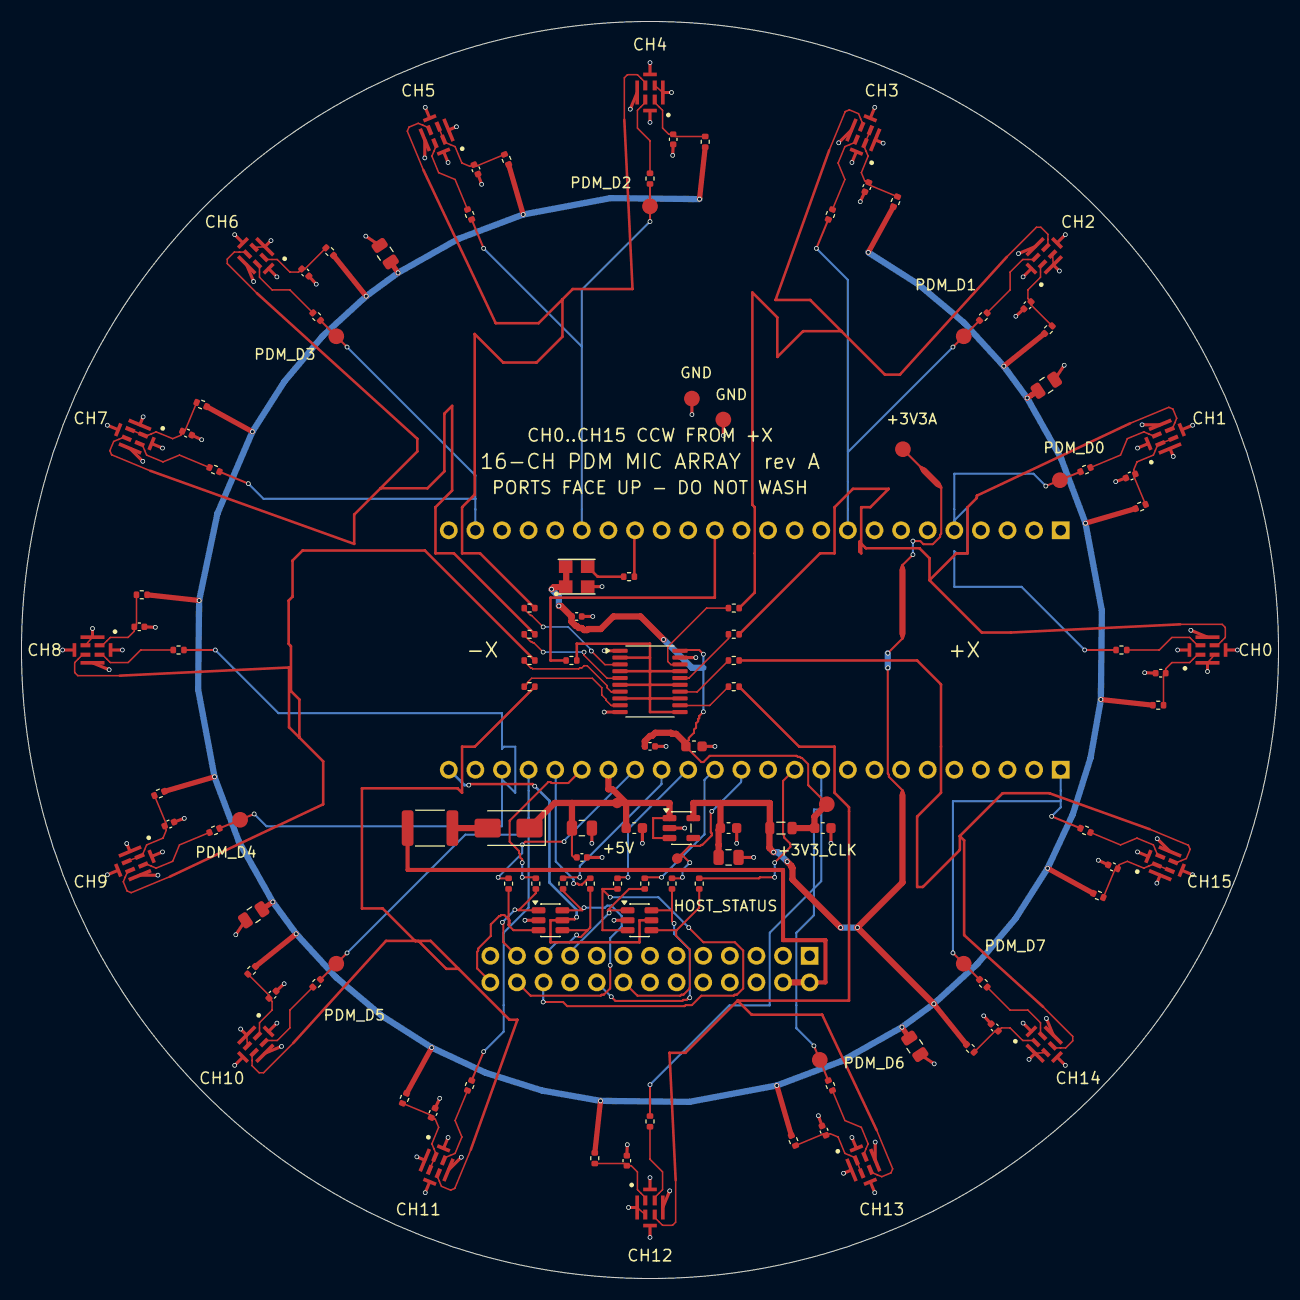
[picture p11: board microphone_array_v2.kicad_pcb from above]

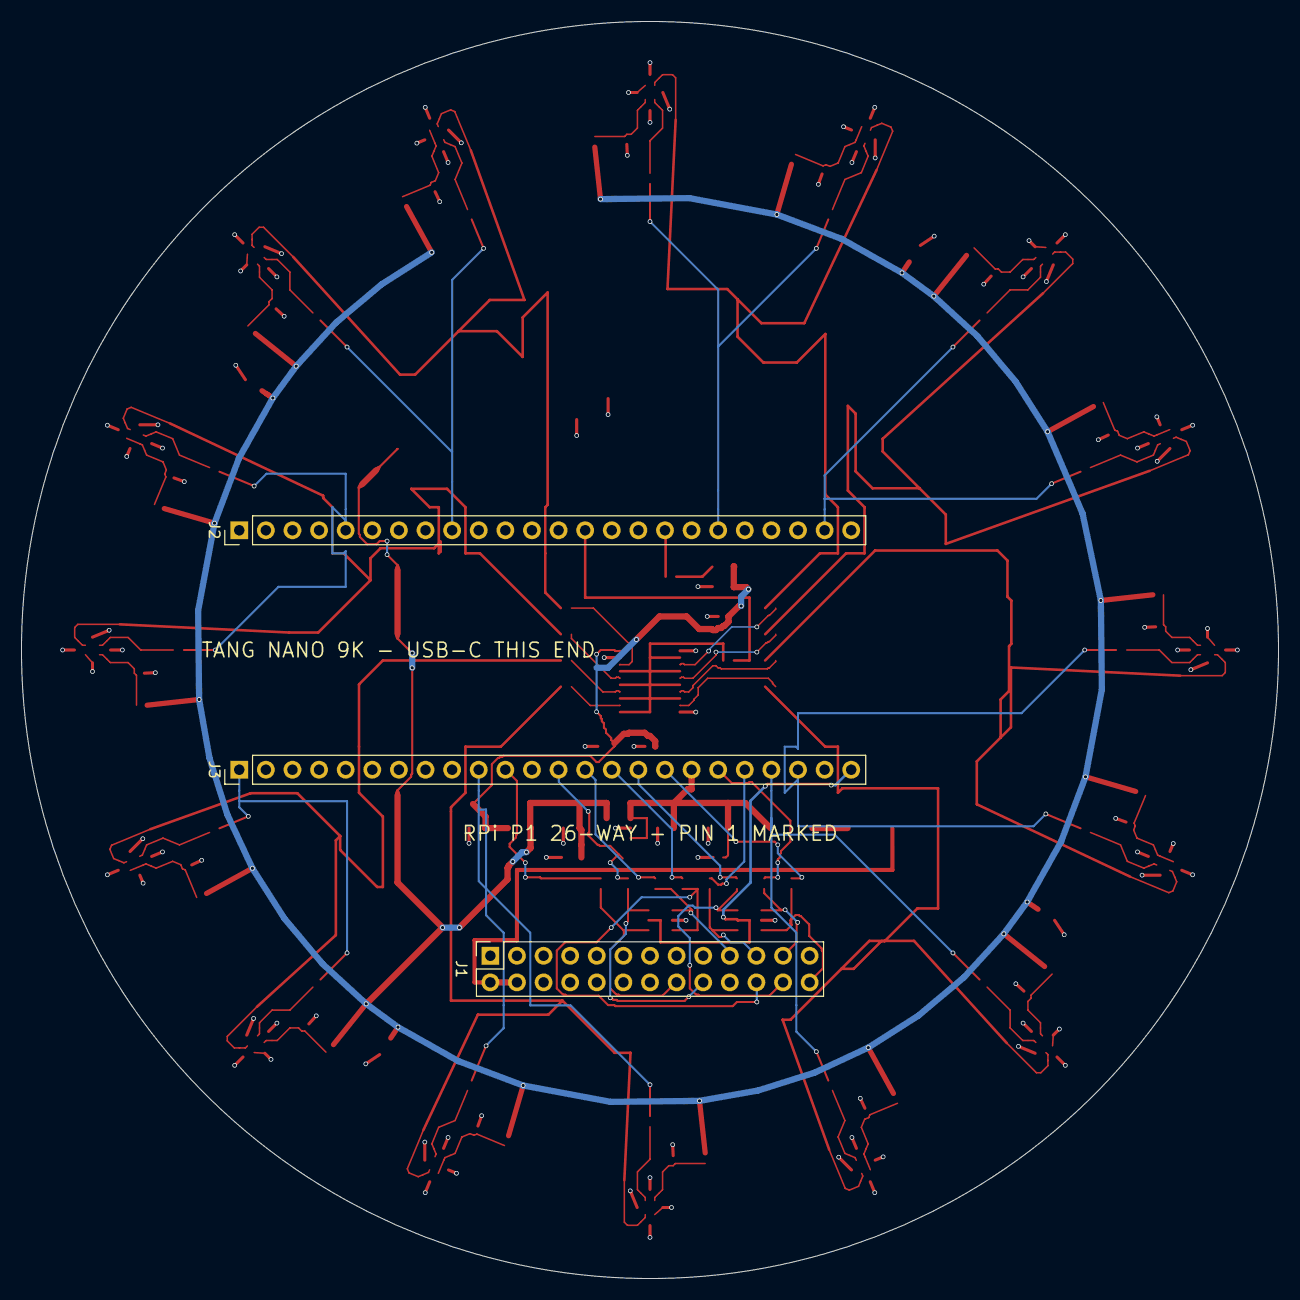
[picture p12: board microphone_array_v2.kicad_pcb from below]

Board: 4 copper layers, 120.0 x 120.0 mm, 120 parts (3 on the bottom side), 83 nets.

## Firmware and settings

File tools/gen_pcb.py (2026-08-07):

"""Build microphone_array_v2.kicad_pcb from the shared netlist and placement.

Stackup rationale: both inner layers are solid ground rather than the more
usual signal/GND/power/signal. The whole board draws about 200 mA, so the
supplies are comfortable on 0.6 mm tracks, and giving every F.Cu and B.Cu trace
an unbroken adjacent reference plane matters far more here than power-plane
impedance would. It also removes any chance of a PDM clock or data line
crossing a plane split.

Ground is a plane net that the autorouter never sees, so this script places an
explicit stitching via plus a short connecting track at every ground pad.
"""

import argparse
import collections
import fnmatch
import itertools
import math
import os
import sys

import pcbnew

import design as d
import netlist as nl

FOOTPRINT_LIBS = {
    "Resistor_SMD": r"C:\Program Files\KiCad\10.0\share\kicad\footprints\Resistor_SMD.pretty",
    "Capacitor_SMD": r"C:\Program Files\KiCad\10.0\share\kicad\footprints\Capacitor_SMD.pretty",
    "Inductor_SMD": r"C:\Program Files\KiCad\10.0\share\kicad\footprints\Inductor_SMD.pretty",
    "Package_TO_SOT_SMD": r"C:\Program Files\KiCad\10.0\share\kicad\footprints\Package_TO_SOT_SMD.pretty",
    "Package_SO": r"C:\Program Files\KiCad\10.0\share\kicad\footprints\Package_SO.pretty",
    "Diode_SMD": r"C:\Program Files\KiCad\10.0\share\kicad\footprints\Diode_SMD.pretty",
    "Fuse": r"C:\Program Files\KiCad\10.0\share\kicad\footprints\Fuse.pretty",
    "Connector_PinHeader_2.54mm": r"C:\Program Files\KiCad\10.0\share\kicad\footprints\Connector_PinHeader_2.54mm.pretty",
    "Connector_PinSocket_2.54mm": r"C:\Program Files\KiCad\10.0\share\kicad\footprints\Connector_PinSocket_2.54mm.pretty",
    "Connector_IDC": r"C:\Program Files\KiCad\10.0\share\kicad\footprints\Connector_IDC.pretty",
    "MountingHole": r"C:\Program Files\KiCad\10.0\share\kicad\footprints\MountingHole.pretty",
    "TestPoint": r"C:\Program Files\KiCad\10.0\share\kicad\footprints\TestPoint.pretty",
}

VIA_DIAMETER = 0.45
VIA_DRILL = 0.30
STITCH_CLEARANCE = 0.55
EDGE_INSET = 0.30
PLANE_INSET = 0.50

GROUND_PLANE_LAYERS = (pcbnew.In1_Cu, pcbnew.In2_Cu)


def mm(value):
    return pcbnew.FromMM(float(value))


def vec(x, y):
    return pcbnew.VECTOR2I(mm(x), mm(y))


def load_footprint(lib_id, project_root):
    nickname, name = lib_id.split(":", 1)
    path = FOOTPRINT_LIBS.get(nickname)
    if path is None:
        path = os.path.join(project_root, f"{nickname}.pretty")
    footprint = pcbnew.FootprintLoad(path, name)
    if footprint is None:
        raise SystemExit(f"footprint not found: {lib_id} (searched {path})")
    return footprint


# Footprints whose library silkscreen is dropped. Populated from the DRC
# result rather than by guesswork; everything else keeps the library legend so
# the board still matches its footprint library.
SILKSCREEN_STRIP = frozenset()


def strip_silkscreen(footprint):
    """Remove silkscreen graphics from a footprint, keeping copper and fab."""
    doomed = [item for item in footprint.GraphicalItems()
              if item.GetLayer() in (pcbnew.F_SilkS, pcbnew.B_SilkS)]
    for item in doomed:
        footprint.Remove(item)


def open_pin_name(ref, pad):
    """Symbol pin name for a deliberately open pin, matching gen_symbols.py."""
    if ref == "U1":
        return "NC"
    if ref == "J1":
        return f"P{pad}_NC"
    labels = d.TANG_J5 if ref == "J2" else d.TANG_J6
    return f"P{pad}_FPGA{labels[int(pad) - 1]}"


def circle_points(radius, count=240, cx=d.PAGE_CX, cy=d.PAGE_CY):
    points = []
    for index in range(count):
        angle = 2.0 * math.pi * index / count
        points.append((cx + radius * math.cos(angle),
                       cy + radius * math.sin(angle)))
    return points


def build(project_root, with_escapes=True):
    """Build the board. `with_escapes=False` omits the pre-routed microphone
    escapes, which is the form handed to FreeRouting - its polyline normaliser
    hangs on them. They are re-applied afterwards by tools/apply_escapes.py."""
    global _MODEL, _RULES, _PROJECT_ROOT
    _MODEL, _RULES = None, None
    _PROJECT_ROOT = project_root
    components, nets = nl.build()
    board = pcbnew.BOARD()
    board.SetCopperLayerCount(4)
    board.SetLayerName(pcbnew.In1_Cu, "GND1")
    board.SetLayerName(pcbnew.In2_Cu, "GND2")

    settings = board.GetDesignSettings()
    settings.SetCopperLayerCount(4)

    # ------------------------------------------------------------------
    # Nets
    # ------------------------------------------------------------------
    net_items = {}
    for name in sorted(nets):
        item = pcbnew.NETINFO_ITEM(board, name)
        board.Add(item)
        net_items[name] = item

    pin_net = {}
    for name, pins in nets.items():
        for ref, pad in pins:
            pin_net[(ref, pad)] = name

    # KiCad gives every deliberately open pin an auto-generated net name in the
    # schematic. Reproducing those names here keeps schematic parity clean
    # instead of leaving 39 net_conflict reports to be waived by hand.
    for ref, pad in nl.expected_unconnected():
        pin_name = open_pin_name(ref, pad)
        name = f"unconnected-({ref}-{pin_name}-Pad{pad})"
        item = pcbnew.NETINFO_ITEM(board, name)
        board.Add(item)
        net_items[name] = item
        pin_net[(ref, pad)] = name

    # ------------------------------------------------------------------
    # Footprints
    # ------------------------------------------------------------------
    placed = {}
    silk_reference = {"J1", "J2", "J3"}
    for component in components:
        ref = component["ref"]
        footprint = load_footprint(component["footprint"], project_root)
        board.Add(footprint)
        # Keep the library nickname so schematic parity can match the symbol's
        # footprint field.
        nickname, name = component["footprint"].split(":", 1)
        footprint.SetFPID(pcbnew.LIB_ID(nickname, name))
        footprint.SetReference(ref)
        footprint.SetValue(component["value"])
        footprint.SetLibDescription(component["description"])
        footprint.SetField("Description", component["description"])
        kx, ky = d.to_kicad(component["x"], component["y"])
        footprint.SetPosition(vec(kx, ky))
        if component["side"] == "bottom":
            footprint.Flip(vec(kx, ky), pcbnew.FLIP_DIRECTION_TOP_BOTTOM)
        footprint.SetOrientationDegrees(component["rot"])
        if component["dnp"]:
            footprint.SetDNP(True)
        if not component["in_bom"]:
            footprint.SetExcludedFromBOM(True)

        for field, value in (("LCSC", component["lcsc"]),
                             ("MPN", component["mpn"]),
                             ("Manufacturer", component["manufacturer"])):
            if value:
                footprint.SetField(field, value)

        # Newly created fields default to being visible on the silkscreen, all
        # stacked on the footprint origin. Hide them and move them to the
        # fabrication layer - they are BOM data, not legend.
        for field in footprint.GetFields():
            if field.GetName() not in ("Reference", "Value"):
                field.SetVisible(False)
                field.SetLayer(pcbnew.B_Fab if footprint.IsFlipped()
                               else pcbnew.F_Fab)

        # The board is dense, so silkscreen designators are kept only for the
        # hand-soldered connectors and the test points. Everything else keeps
        # its designator on the fabrication layer, where JLCPCB's assembly data
        # and the CPL still carry it.
        # Two-terminal passives keep no silkscreen outline. At this density
        # their tiny side bars only collide with neighbouring pads, and they
        # carry no orientation information that assembly needs - JLCPCB places
        # from the CPL. Silkscreen is retained where it means something: the
        # microphone pin-1 mark, the diode polarity bar, the IC and oscillator
        # pin-1 marks, and the connectors.
        if ref in SILKSCREEN_STRIP:
            strip_silkscreen(footprint)

        back = footprint.IsFlipped()
        if ref not in silk_reference:
            footprint.Reference().SetLayer(pcbnew.B_Fab if back else pcbnew.F_Fab)
        if ref.startswith("TP"):
            # The full net name stays on the fabrication layer; a short legend
            # is drawn separately so neighbouring labels do not collide.
            footprint.Value().SetLayer(pcbnew.F_Fab)

        for pad in footprint.Pads():
            name = pin_net.get((ref, pad.GetNumber()))
            if name:
                pad.SetNet(net_items[name])
        placed[ref] = footprint

    # ------------------------------------------------------------------
    # Board outline and ground planes
    # ------------------------------------------------------------------
    outline = pcbnew.PCB_SHAPE(board)
    outline.SetShape(pcbnew.SHAPE_T_CIRCLE)
    outline.SetStart(vec(d.PAGE_CX, d.PAGE_CY))
    outline.SetEnd(vec(d.PAGE_CX + d.BOARD_RADIUS, d.PAGE_CY))
    outline.SetLayer(pcbnew.Edge_Cuts)
    outline.SetWidth(mm(0.1))
    board.Add(outline)

    for layer in GROUND_PLANE_LAYERS:
        zone = pcbnew.ZONE(board)
        zone.SetLayer(layer)
        zone.SetNet(net_items["GND"])
        zone.SetIsFilled(False)
        zone.SetLocalClearance(mm(0.25))
        zone.SetMinThickness(mm(0.2))
        zone.SetPadConnection(pcbnew.ZONE_CONNECTION_FULL)
        polygon = zone.Outline()
        polygon.NewOutline()
        for x, y in circle_points(d.BOARD_RADIUS - PLANE_INSET):
            polygon.Append(mm(x), mm(y))
        board.Add(zone)

    reset_short_guard(board)
    strap_count = link_microphone_straps(board, placed, pin_net, net_items)
    if with_escapes:
        strap_count += route_microphone_escapes(board, placed, pin_net, net_items)
        strap_count += route_channel_local(board, placed, pin_net, net_items)
        strap_count += route_supply_ring(board, placed, pin_net, net_items)
        # Power before the clocks. The regulator's feed out to the supply ring
        # has one workable route in each direction and the clock branches have
        # hundreds, so whichever is laid down first keeps its route - and it
        # should be the one with nowhere else to go.
        strap_count += route_supply_ring_feed(board, placed, pin_net, net_items)
        strap_count += route_power_block(board, placed, pin_net, net_items)
        # The clock spine before the branches: both are declared critical, and
        # the spine has one corridor each way while a branch has hundreds.
        # Taps first: each clamp pin has one way off its pad and a short list
        # of columns to turn up in, while the bias rail between the two arrays
        # can go almost anywhere. The one with no choice chooses first.
        strap_count += reserve_esd_ground(board, placed, pin_net, net_items)
        strap_count += route_esd_taps(board, placed, pin_net, net_items)
        strap_count += route_esd_bias_link(board, placed, pin_net, net_items)
        strap_count += route_master_clock(board, placed, pin_net, net_items)
        strap_count += route_clock_root(board, placed, pin_net, net_items)
        strap_count += route_clock_branches(board, placed, pin_net, net_items)
        strap_count += route_data_spokes(board, placed, pin_net, net_items)
        # route_host_block() is written but not yet called. The stack order is
        # now right - connector, ESD, resistors, socket, all flowing inward -
        # but routing *through* a specific ESD pin still needs a proper escape:
        # each array has two signal pins per side in one column, so a track
        # cannot simply pass both. See docs/status.md.
    else:
        strap_count += reserve_microphone_corridors(board, placed, pin_net,
                                                    net_items)
    stitch_count = place_ground_stitching(board, placed, pin_net, net_items)
    add_silkscreen(board)

    # Manufacturing keep-outs, so the autorouter cannot place a via where an
    # ordinary tented/plugged via would be unreliable, and locks, so it cannot
    # re-open anything decided above.
    redundant = drop_redundant_copper(board)
    import manufacturing as mfg
    rules = mfg.load_rules(project_root)
    keepouts = mfg.add_keepouts(board, rules)
    locked = mfg.lock_generated_copper(board)
    if redundant:
        print(f"dropped {redundant} segments laid over copper of their own net")
    print(f"manufacturing keep-outs {keepouts}  locked copper objects {locked}")

    filler = pcbnew.ZONE_FILLER(board)
    filler.Fill(board.Zones())

    path = os.path.join(project_root, "microphone_array_v2.kicad_pcb")
    board.Save(path)
    apply_project_settings(project_root)

    # The critical routes above are only critical if something checks them.
    import critical_nets
    outcome = critical_nets.verify(board)
    for row in outcome:
        if not row["pass"]:
            print("critical route {} fails {}: {} (limit {})".format(
                row["rule"], row["check"], row["value"], row["limit"]))
    failures = [row for row in outcome if not row["pass"]]
    print("critical net checks {} passed, {} failed".format(
        len(outcome) - len(failures), len(failures)))
    return path, len(components), len(nets), stitch_count, strap_count


# The MSM261DHP006 land pattern encloses its four signal pads in a ground ring
# with only a 0.40 mm straight gap, so nothing escapes in a straight line. The
# open diagonal corner between the side bar and the end bar is 0.566 mm wide,
# which fits a 0.15 mm track with 0.15 mm clearance and nothing wider. The
# three classes that reach a microphone pad are sized for that escape; they
# carry a few milliamps at most, so the narrower track costs nothing.
NET_CLASSES = [
    # name, track width, clearance, via diameter, via drill
    ("Default", 0.20, 0.20, 0.45, 0.30),
    # 0.15 mm clearance because the microphone escape has to pass a GND pad on
    # both sides of a 0.566 mm diagonal channel; the ground zones keep their
    # own 0.25 mm local clearance for the fill.
    ("PLANE", 0.60, 0.15, 0.60, 0.35),
    ("POWER", 0.60, 0.25, 0.60, 0.35),
    # TANG_3V3 is not a distribution rail. It comes out of the Tang Nano and
    # its whole load is the bias pin of two USBLC6-4SC6 clamps - reverse
    # leakage, 1 uA each at most - plus a test point. POWER's 0.60 mm track
    # with 0.25 mm clearance needs a 1.10 mm corridor, and there is none:
    # pin 5 of a SOT-23-6 sits between two pads 0.35 mm away, and the run
    # across to the second array threads the host fan. 0.25 mm carries about
    # an amp on 1 oz outer copper, which is six orders of magnitude of margin
    # on a microamp load, so the rail is sized for its duty instead.
    ("MODULE_RAIL", 0.25, 0.20, 0.45, 0.30),
    ("MIC_SUPPLY", 0.15, 0.15, 0.45, 0.30),
    # MIC_DOUT is split out of PDM_DATA so the finished per-channel routing can
    # be handed to the autorouter as an ignored class while PDM_D stays live.
    ("MIC_DATA", 0.15, 0.15, 0.45, 0.30),
    ("MANUAL_CRITICAL", 0.15, 0.15, 0.45, 0.30),
    ("PDM_DATA", 0.15, 0.15, 0.45, 0.30),
    ("HOST", 0.20, 0.20, 0.45, 0.30),
]

NET_CLASS_PATTERNS = [
    ("PLANE", "GND"),
    ("POWER", "+5V"), ("POWER", "+3V3A"), ("POWER", "+3V3_CLK"),
    ("POWER", "PI_5V"), ("POWER", "5V_FUSED"),
    ("MODULE_RAIL", "TANG_3V3"),
    ("MIC_SUPPLY", "MIC_VDD_*"),
    ("MANUAL_CRITICAL", "AUDIO_MCLK"), ("MANUAL_CRITICAL", "MCLK_OSC"),
    ("MANUAL_CRITICAL", "PDM_CLK_*"),
    ("PDM_DATA", "PDM_D?"), ("MIC_DATA", "MIC_DOUT_*"),
    # Listed explicitly rather than as "PI_*", which would also capture PI_5V
    # and put that net in two classes at once.
    ("HOST", "SPI_*"), ("HOST", "HOST_*"),
    ("HOST", "PI_SCLK"), ("HOST", "PI_MOSI"), ("HOST", "PI_MISO"),
    ("HOST", "PI_CS_N"), ("HOST", "PI_IRQ"), ("HOST", "PI_SYNC"),
    ("HOST", "PI_RESET_N"), ("HOST", "PI_STATUS"),
]

# Conservative JLCPCB standard four-layer profile.
BOARD_RULES = {
    "max_error": 0.005,
    "min_clearance": 0.127,
    "min_connection": 0.127,
    "min_copper_edge_clearance": 0.30,
    "min_hole_clearance": 0.25,
    "min_hole_to_hole": 0.25,
    "min_microvia_diameter": 0.20,
    "min_microvia_drill": 0.10,
    "min_resolved_spokes": 2,
    "min_silk_clearance": 0.15,
    "min_text_height": 1.0,
    "min_text_thickness": 0.15,
    "min_through_hole_diameter": 0.30,
    "min_track_width": 0.127,
    "min_via_annular_width": 0.075,
    "min_via_diameter": 0.45,
    "solder_mask_to_copper_clearance": 0.0,
    "use_height_for_length_calcs": True,
}


# Checks KiCad ignores by default and this board does not. Saving from pcbnew
# resets the severities along with everything else in the project file, so a
# check that is not named here is a check that quietly stops running after the
# next build - which is how five of them came to be off.
RULE_SEVERITIES = {
    "footprint_filters_mismatch": "warning",
    "footprint_type_mismatch": "warning",
    "missing_courtyard": "warning",
    "tuning_profile_track_geometries": "warning",
    # Enabled, and the findings it raises are waived one by one in
    # verification/boards/live.json rather than the rule being turned off. The
    # router lands a track end on its own grid, which on a handful of nets is
    # 0.1 mm from the via centre it connects to - a 0.2 mm track well inside a
    # 0.45 mm annulus, connected and clear. No router setting centres them and
    # correcting them by hand is editing routed copper, which this board's
    # process forbids; but a waiver names each one and expires the moment any
    # of them moves, which a disabled rule would not.
    "track_not_centered_on_via": "warning",
}
ERC_SEVERITIES = {
    "single_global_label": "warning",
    "four_way_junction": "warning",
    "simulation_model_issue": "warning",
    "footprint_filter": "warning",
}


def apply_project_settings(project_root):
    """Re-apply design rules and net classes after pcbnew rewrites the project.

    Saving a board from the Python API resets the sibling .kicad_pro to
    defaults, so the curated rules are written back here rather than being
    maintained by hand.
    """
    import json

    path = os.path.join(project_root, "microphone_array_v2.kicad_pro")
    with open(path, "r", encoding="utf-8") as handle:
        project = json.load(handle)

    design = project.setdefault("board", {}).setdefault("design_settings", {})
    design.setdefault("rules", {}).update(BOARD_RULES)
    design.setdefault("rule_severities", {}).update(RULE_SEVERITIES)
    project.setdefault("erc", {}).setdefault(
        "rule_severities", {}).update(ERC_SEVERITIES)
    design["track_widths"] = [0.0, 0.127, 0.20, 0.25, 0.30, 0.60, 1.00]
    design["via_dimensions"] = [
        {"diameter": 0.0, "drill": 0.0},
        {"diameter": 0.45, "drill": 0.30},
        {"diameter": 0.60, "drill": 0.35},
    ]

    classes = []
    for name, track, clearance, via_d, via_drill in NET_CLASSES:
        classes.append({
            "bus_width": 12, "clearance": clearance,
            "diff_pair_gap": 0.25, "diff_pair_width": 0.2,
            "line_style": 0, "microvia_diameter": 0.3, "microvia_drill": 0.1,
            "name": name,
            "pcb_color": "rgba(0, 0, 0, 0.000)",
            "schematic_color": "rgba(0, 0, 0, 0.000)",
            "track_width": track, "via_diameter": via_d, "via_drill": via_drill,
            "wire_width": 6,
        })

    project["net_settings"] = {
        "classes": classes,
        "meta": {"version": 4},
        "net_colors": None,
        "netclass_assignments": None,
        "netclass_patterns": [{"netclass": cls, "pattern": pattern}
                              for cls, pattern in NET_CLASS_PATTERNS],
    }

    with open(path, "w", encoding="utf-8") as handle:
        json.dump(project, handle, indent=2)
        handle.write("\n")


def mm_to_f(value):
    """Internal units to millimetres, as a float."""
    return value / 1e6


def legalise_stitch(model, pad_position, preferred, diameter, drill, width,
                    side):
    """The preferred spot if it is legal, else the nearest one that is.

    Searches outward along the preferred direction first so the intent behind
    the choice survives, then sweeps around the pad. Returns None when the pad
    has nowhere legal at all, which is a generator bug worth failing on rather
    than a via worth placing illegally.
    """
    px, py = mm_to_f(pad_position.x), mm_to_f(pad_position.y)
    cx, cy = mm_to_f(preferred.x), mm_to_f(preferred.y)

    def ok(x, y):
        return (model.via_ok(x, y, diameter, drill, "GND")
                and model.track_ok(px, py, x, y, width, "GND", side))

    if ok(cx, cy):
        return preferred

    dx, dy = cx - px, cy - py
    base = math.hypot(dx, dy)
    if base < 1e-9:
        dx, dy, base = 0.0, 1.0, 1.0
    ux, uy = dx / base, dy / base
    for extra in [0.05 * i for i in range(1, 25)]:
        x, y = px + ux * (base + extra), py + uy * (base + extra)
        if ok(x, y):
            return pcbnew.VECTOR2I(pcbnew.FromMM(x), pcbnew.FromMM(y))
    for radius in [round(base + 0.05 * i, 3) for i in range(0, 30)]:
        for step in range(48):
            angle = 2 * math.pi * step / 48
            x, y = px + radius * math.cos(angle), py + radius * math.sin(angle)
            if ok(x, y):
                return pcbnew.VECTOR2I(pcbnew.FromMM(x), pcbnew.FromMM(y))
    return None
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

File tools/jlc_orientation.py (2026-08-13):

"""Derive each part's library-zero offset from JLCPCB's own footprint.

A placement file says how far to turn a part from the orientation the assembly
house holds it in. That orientation is a property of *their* library, not of
ours, and where the two disagree every instance of the part is fitted turned by
the difference. Guessing it from a package name is how a regulator ends up
backwards: JLC's SOT-23-5 and SOT-23-6 libraries do not share a zero, so any
table indexed by "SOT-23" is wrong for one of them.

So nothing here is guessed. For each LCSC number this fetches the footprint
JLCPCB actually uses - EasyEDA is their EDA and serves it - normalises the pads
into a top view in millimetres, and compares them pad number by pad number
against the same part's KiCad footprint as placed on this board. Each candidate
offset is scored by the worst angular disagreement over all pads, so the answer
is decided by every pin rather than by pin 1 alone: a pin-1 match cannot tell a
rotation from a mirror.

Two files are frozen per part under fabrication/jlc_orientation/. The response
body exactly as served is kept under raw/, and beside it a normalised extract
recording the source URL, the retrieval date, the response length and its
SHA-256. The extract is not the response and is never described as one: it is
derived from it, and every offline command re-derives it rather than trusting
it, so tampering with the raw payload, with the extraction, or with the
registry's offset all fail rather than pass.

    tools/jlc_orientation.py freeze [LCSC ...]   fetch and record the evidence
    tools/jlc_orientation.py report              score every frozen part
    tools/jlc_orientation.py check               non-zero if any offset moved
    tools/jlc_orientation.py check-live          frozen evidence vs JLC today

Only freeze and check-live use the network. report and check read the frozen
files alone, so the test suite and the clean release never reach upstream, and
JLC changing their library is reported as upstream drift rather than as
corruption of what is committed here.
"""

from __future__ import annotations

import argparse
import datetime
import hashlib
import json
import math
import os
import sys
import urllib.request

HERE = os.path.dirname(os.path.dirname(os.path.abspath(__file__)))
FIXTURES = os.path.join(HERE, "fabrication", "jlc_orientation")
BOARD = os.path.join(HERE, "microphone_array_v2.kicad_pcb")
SOURCE = "https://easyeda.com/api/products/{lcsc}/components?version=6.4.19.5"

# EasyEDA stores footprint geometry in units of 10 mil, with the canvas Y axis
# running downward like a screen. Both facts are needed to read a pad position
# as a point in a top view.
UNIT_MM = 0.254
CANDIDATES = (0.0, 90.0, 180.0, 270.0)
# Two land patterns for one part differ in pad size and row spacing, so pad
# directions never agree exactly. They agree to a few degrees under the right
# rotation and are 90 or 180 out under any other, so the gap between best and
# runner-up is what decides, not the absolute error.
MAX_BEST_ERROR_DEG = 20.0
MIN_MARGIN_DEG = 45.0

HEADERS = {
    "User-Agent": ("Mozilla/5.0 (Windows NT 10.0; Win64; x64) "
                   "AppleWebKit/537.36 (KHTML, like Gecko) Chrome/128.0 "
                   "Safari/537.36"),
    "Accept": "application/json, text/plain, */*",
    "Accept-Language": "en-US,en;q=0.9",
    "Referer": "https://easyeda.com/",
    "Origin": "https://easyeda.com",
}


# ---------------------------------------------------------------------------
# JLC's library, normalised
# ---------------------------------------------------------------------------

def fetch(lcsc, timeout=45):
    """The raw response body for one part, exactly as served."""
    url = SOURCE.format(lcsc=lcsc)
    request = urllib.request.Request(url, headers=HEADERS)
    with urllib.request.urlopen(request, timeout=timeout) as response:
        return url, response.read()


def extract(lcsc, raw):
    """Read a raw response body. {"mpn", "package", "pads"}, nothing else.

    Deliberately a pure function of the bytes: this is what makes the frozen
    extract checkable rather than merely present. EasyEDA's PAD record is a
    tilde-separated row whose third and fourth fields are the pad centre and
    whose ninth is the pad number. Y is negated here so that a larger value
    means further up, which is how every other coordinate in this project is
    read.
    """
    document = json.loads(raw.decode("utf-8"))
    result = document.get("result") or {}
    package = result.get("packageDetail") or {}
    data = package.get("dataStr") or {}
    shapes = data.get("shape") or []
    parameters = (data.get("head") or {}).get("c_para") or {}

    pads = {}
    for shape in shapes:
        if not shape.startswith("PAD~"):
            continue
        field = shape.split("~")
        number = field[8].strip()
        if not number:
            continue
        pads[number] = [round(float(field[2]) * UNIT_MM, 6),
                        round(-float(field[3]) * UNIT_MM, 6)]
    if not pads:
        raise ValueError("{}: the response carries no pads".format(lcsc))

    return {
        "mpn": result.get("title", "").strip(),
        "package": parameters.get("package", "").strip(),
        "pads": dict(sorted(pads.items(), key=_pad_sort)),
    }


def normalise(lcsc, url, raw, retrieved_utc=None):
    """The extract, plus where the bytes it came from were obtained."""
    fields = extract(lcsc, raw)
    return {
        "kind": "normalised extract",
        "note": "Derived from the raw response body, which is committed "
                "verbatim at raw_file. This file is not the response. Every "
                "offline command re-derives these pads from that file and "
                "fails on a disagreement.",
        "lcsc": lcsc,
        "mpn": fields["mpn"],
        "package": fields["package"],
        "source_url": url,
        "retrieved_utc": retrieved_utc or datetime.datetime.now(
            datetime.timezone.utc).strftime("%Y-%m-%dT%H:%M:%SZ"),
        "raw_file": os.path.relpath(raw_path(lcsc), HERE).replace("\\", "/"),
        "raw_bytes": len(raw),
        "raw_sha256": hashlib.sha256(raw).hexdigest(),
        "units": "millimetres, top view, Y up; EasyEDA stores 10-mil units "
                 "with Y down and both conversions are applied here",
        "derivation": "PAD~ records of result.packageDetail.dataStr.shape; "
                      "field 3 and field 4 are the pad centre in 10-mil units "
                      "and field 9 is the pad number",
        "pads": fields["pads"],
    }


def _pad_sort(item):
    try:
        return (0, int(item[0]))
    except ValueError:
        return (1, item[0])


def fixture_path(lcsc):
    return os.path.join(FIXTURES, "{}.json".format(lcsc))
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

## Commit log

2026-08-02 This is where Opus 5 stopped
    [board.dsn, merged17.kicad_pcb, microphone_array_v2.kicad_pcb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]
2026-08-03 Asked Claude to remove routes that hit each other, then it ran out of tokens
    [microphone_array_v2.kicad_pcb, microphone_array_v2.kicad_sch]
2026-08-03 Used auto router and removed test pads
    [microphone_array_v2.kicad_pcb]
2026-08-03 Claude fixup
    [microphone_array_v2.kicad_pcb, microphone_array_v2.kicad_sch]
2026-08-03 Placed test points, generated release
    [bom.csv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]
2026-08-04 Add better automated tests
    [board.dsn, bom.csv, merged17.kicad_pcb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]
2026-08-04 Pin line endings and stop normalising production output
    The repository used `* text=auto` with no eol setting, so a Windows checkout
    produced CRLF for every text file while the frozen-fixture digests had been
    taken from an LF working tree. That is what the 30 fixture "mismatches" were:
    Git normalisation, not a change to Rev A.
    Design sources are now `eol=lf`, so a checkout is byte-identical on every
    platform. Everything under a release directory is `-text`, so Gerbers, drills,
    the fabrication archive and the BOM/CPL keep the exact bytes whose SHA-256 the
    release manifest records; normalising those after generation would invalidate
    the manifest.
    PRE_NORMALIZATION_HASHES.json records the dig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
    [bom.csv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]
2026-08-04 More pcb tests
    [board.dsn, bom.csv, merged17.kicad_pcb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]
2026-08-05 More tests
    [bom.csv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]
2026-08-05 Further updates to tests
    [microphone_array_v2-B_Cu.gbr, microphone_array_v2-B_Mask.gbr, microphone_array_v2-B_Paste.gbr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]
2026-08-05 More test updates
    [microphone_array_v2-B_Cu.gbr, microphone_array_v2-B_Mask.gbr, microphone_array_v2-B_Paste.gbr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]
2026-08-05 Next board rev
    [microphone_array_v2.kicad_pcb]
2026-08-05 Partial Board Redesign
    [reroute_signals_only.kicad_pcb, reroute_via_clean.kicad_pcb]
2026-08-06 Build board
    [microphone_array_v2.kicad_pcb, microphone_array_v2.kicad_sch]
2026-08-07 New board rev
    [bom.csv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]
2026-08-08 Try to fix CPL
    [bom.csv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]
2026-08-08 Name fabrication layers for the fab, not for X2 metadata
    JLCPCB does not reliably read Gerber X2 FileFunction attributes. The export
    shipped its inner copper as GND1.gbr and GND2.gbr and let the attributes carry
    their role, so nothing in the upload identified them as copper at all - a
    four-layer board that can be quoted and built as two-layer.
    The export now drops X2 entirely (--no-x2 --no-netlist
    --disable-aperture-macros, and no job file) and says everything in the
    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
    [microphone_array_v2-B_Cu.gbr, microphone_array_v2-B_Mask.gbr, microphone_array_v2-B_Paste.gbr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]
2026-08-08 Keep aperture macros: nothing needed them disabled
    --disable-aperture-macros made KiCad draw every rounded pad corner as a single
    chord instead of an arc. The front mask went from 90 apertures to 11 and lost
    1.4% of its area, corners were chamfered by up to 0.0732 mm, and matching the
    export against the board needed clearance_match_mm widened from 0.01 to
    0.085 mm to absorb it.
    None of that bought anything. The four-layer identification is carried
    entirely by the filenames - .GTL, .G2L, .G3L, .GBL, with --no-x2 and no job
    file - and that is untouched. So the flag goes and the tolerance goes back to
    0.01 mm, where VIA.NATIVE_GERBER_AGREEMENT again matches all 184 vias object
    by object.
    F.Ma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
    [microphone_array_v2-NPTH.drl, microphone_array_v2-PTH.drl, microphone_array_v2.GBL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]
2026-08-12 Correct CPL orientations at generation, not in production review
    JLCPCB revised 52 placements on the first upload. Two unrelated causes, and
    they need separating because conflating them turns parts that were right.
    48 of them were angle handling. KiCad writes rotations in (-180, 180] and this
    board is a 16-way polar array, so 30 placements shipped negative and 18 more at
    22.5-degree fractions. Every angle is now normalised into [0, 360). No offset
    is involved and none is created: an offset invented to make a negative angle
    positive would turn the part.
    That those 48 need no offset is measured, not assumed. JLCPCB corrected 11 of
    16 microphones, 11 of 16 damping resistors, 11 of 16 supply r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
    [cpl.csv, microphone_array_v2-NPTH.drl, microphone_array_v2-PTH.drl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]
2026-08-12 Make the CPL orientation registry an authority, not a self-check
    The offsets shipped in commit 9f11eb8 were right, but nothing outside the
    generator could tell you so. The gate read the same table the generator had
    applied, which proves only that a program can apply its own table twice, and a
    part with no entry silently took a zero offset - the one failure mode that
    looks identical to "checked, needs nothing".
    Every populated part number now carries an explicit reviewed entry, all fifteen
    of them, including the twelve whose offset is zero. Generation raises on a part
    with no entry instead of assuming anything, so an unreviewed part cannot reach a
    machine.
    Each entry is backed by JLCPCB's o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
    [jlc_orientation.py]
2026-08-12 Commit the orientation evidence instead of describing it
    Five gaps in the registry that commit 9f11eb8 left, none of which change an
    offset: U1 is still +180, U2 and U3/U4 still -90, and the shipped angles are
    still 180/270/270/270.
    Raw evidence. The fixtures held pad extracts and the digest of a response body
    that was nowhere in the repository - a claim about evidence rather than the
    evidence. Each part's EasyEDA response is now committed byte for byte under
    fabrication/jlc_orientation/raw/, and the extract beside it is re-derived from
    that body every time it is read. Scoring reads the body, not the extract, so
    all three edits fail: the raw file breaks its recorded digest, the extract stop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
    [jlc_orientation.py]
2026-08-13 Install one release, and check that it is one release
    generated/release/ held artifacts from two clean-room runs. The validation
    report and clean-room record came from attempt 20260812T163729Z; the archive,
    release manifest and check reports came from an earlier one, under a different
    source closure. Every file was well formed. The set was a lie, and a note
    explaining the discrepancy was left beside it - which is the part worth fixing,
    because a note is not a check.
    The package is now one run, installed whole. The archive digest changed, as
    expected. Before accepting it, every Gerber and drill was compared against the
    previous release with only KiCad's own timestamp lines removed: all 13 ar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
    [microphone_array_v2-NPTH.DRL, microphone_array_v2-NPTH.drl, microphone_array_v2-PTH.DRL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]
2026-08-13 Make provenance mean the same thing on another machine
    An independent run of 62fc701 from a fresh Linux checkout found four things
    that were only true here. None of them were about the board.
    Evidence paths were matched with os.path.basename. A path recorded on Windows
    is data, not a path on the reading machine, so on Linux the whole string reads
    as one filename and the archive ARCH.CONTENTS validated could never be found -
    the same package was coherent on one platform and incoherent on the other.
    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
    [microphone_array_v2-NPTH.DRL, microphone_array_v2-PTH.DRL, microphone_array_v2.GBL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]
2026-08-16 Correct what the closure identifies, and freeze the fixture properly
    Two things that were true only by coincidence.
    The configuration identity excluded whole manifest objects because each held a
    path somewhere. It excluded more than the clean room rewrites: `sources` and
    `tools` are copied through untouched, and only two of `fixture`'s leaves move.
    So pointing the release at candidates/reroute_via_clean.kicad_pcb, or emptying
    fixture.reject_globs, changed nothing the closure could see.
    The excluded set is now exactly the leaves derive_manifest assigns, and it is
    owned by pcbqa.cleanroom rather than by a board file - a manifest may name a
    subset of it and is refused if it names anything els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
    [bom.csv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]
2026-08-17 Describe the module interface this board actually has
    The Tang Nano 9K assignment table was wrong in ten of its twenty-one rows, and
    wrong in a way that would have cost a bring-up session: it put SPI_SCLK,
    SPI_MOSI and SPI_CS_N on the upper socket row, when every SPI line is on the
    lower one. SPI_MISO, HOST_IRQ, HOST_SYNC, HOST_STATUS, HOST_RESET_N, PDM_D7 and
    PDM_D6 were each on the right row at the wrong position. Ten of the FPGA pin
    numbers were wrong too - SPI_MOSI is 73 and not 41, PDM_D7 is 63 and not 75.
    Every row is now taken from TANG_NET_MAP in tools/design.py, which is what
    generates the board, and all twenty-one were checked back against
    microphone_array_v2.kicad_pcb pad by pad.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
